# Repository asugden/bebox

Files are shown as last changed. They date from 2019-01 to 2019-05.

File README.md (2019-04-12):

#BEBOX

BeBox is a collection of tools for systems neuroscience. It includes three parts: designs for 3d printing, circuits and printed circuit boards (PCBs) for behavioral manipulation, and the Arduino code necessary for those circuits.

Many people are interested in only the 3d designs. In that case, all necessary hardware components are listed in the 3d designs directory. If you are interested in electronics, the BeBox Spritz and the BeBox Syringe Pump can both be used indepent of the BeBox system. The syringe pump can be integrated with BeBox. To start with BeBox, one has to order the boards (links can be found in the pcb directory), which come in orders of 3 from OSH Park, my preferred supplier. Note that BeBox is connected by 4-conductor headphone cables. They can be a bit hard to find. 3-conductor cables will not work.

##3D DESIGNS:
__All necessary components are listed in the README in the 3d directory.__

- .stl files  are final output files to be used with 3D printers.
- .scad files  are files written in OpenSCAD which define the .stl files and can be edited
- Some designs are made in Fusion 360 and are available upon request.

###bebox
- bebox bnc bottom.stl  the bottom of a case to hold bnc connectors for bebox
- bebox bnc top.stl  the top of the case to hold bnc connectors for bebox, which can have magnets inserted to allow stacking
- bebox button bottom.stl  the bottom of a case to hold bebox buttons, which also reports licks
- bebox button top.stl  the top of the case to hold bebox buttons
- bebox button 1.stl  a button cap with the number 1
- bebox button 2.stl  a button cap with the number 2
- bebox button 3.stl  a button cap with the number 3
- bebox button 4.stl  a button cap with the number 4
- bebox button e.stl  a button cap with the number e, for ensure
- bebox button q.stl  a button cap with the letter q, for quinine
- bebox main bottom.stl  the bottom of the case to hold the main bebox board
- bebox main top.stl  the top of the case to hold the main bebox board

###lickspout
__NOTE:__ the lickspouts should be printed with conductive PLA if conductive measurement is desired. The lickspout base should be printed in regular PLA. Conductive PLA plastic can be found at https://www.proto-pasta.com/collections/exotic-composite-pla/products/conductive-pla

- lickspout bitube.stl  a pre-made file to be printed with conductive filament that has two tubes, one regularly used for ensure high-calorie milkshake and one used for quinine diluted in water. This is designed for Tygon tubing of 1/16 inch inner diameter and 1/8 inch outer diameter (1.6 mm ID/3.2 mm OD). 
- lickspout unitube.stl  a pre-made file to be printed with conductive filament that has a single tube with a collection area, for training on only a high-calorie milkshake
- lickspout.scad  the file used to create both lickspout bitube and lickspout unitube. Adjustments can be made to the tube diameters at the top. Note that the curved pipe library is required for making changes: https://www.thingiverse.com/thing:71464
- lickspout bitube water.stl  a pre-made file to be printed with conductive filament that has two narrow-diameter tubes. The input tubing should be the same diameter, but the flow rate is decreased
- lickspout water.scad  the file used to create lickspout bitube water.stl. This, too, depends on the curved pipe library
- utilities.scad  a set of useful functions for OpenSCAD

###syringe-pump
The syringe pump is designed to tightly fit 20 ml syringes. All necessary mechanical and electrical components are listed in the README of the syringe 

- syringe pump box.stl  a file that defines the enclosure of the syringe pump including the motor and carriage
- syringe pump carriage.stl  the carriage that rides along bearings to compress the syringe. Note that it should be printed vertically rather than on a flat face.

###wheel
- wheel.stl  a pre-made file that can be printed on an average FDM printer with minimal layer heights. This requires two M4 nuts to be embedded and two M4x10 bolts to pinch the axles. I recommend using black PLA for the wheel as other colors may not correctly block the IR light of a beam breaker. We had problems with gray PLA being transparent to IR light.
- wheel axle.stl  a pre-made file of a short axle piece used to attach the wheel to the wheel holder. 2 are required
- wheel holder.stl  a pre-made file of a suspension system for the wheel, designed to fit into standard Thorlabs pieces. Requires two bearings from McMaster-Carr catalog number 57155K323 at $5.70 each to be inserted into the large central holes with the flanges outward. We hot glue them in, taking care not to get the glue into the bearings.
- wheel.scad  the file used to create wheel.stl. The wheel height, diameter, and tab spacing can all be changed. Note that a finer tab spacing requires narrower LED beam break detectors-- do not change without changing the encoder board.
- wheel holder.scad  the file used to create wheel axle.stl. The spring width, length, and thickness can all be adjusted and the wheel position will remain constant.

###wheel-accessories
- wheel run stopper.stl  a pre-made file that fits into a thorlabs part and applies some resistance to the wheel without disrupting its low inertia/springiness
- wheel run stopper.scad  the file used to create wheel run stopper.stl

###wheel-encoder
__NOTE:__ will be udpated in the near future

- wheel arduino holder.stl  a file to hold two LED beam breakers adjacent to the wheel
- wheel encoder board holder.stl  a file to allow an arduino to be bolted on to the holder such that it can be held next to the wheel

##ARDUINO CODE:
__NOTE:__ Has not yet been made compatible with the new BeBox system. Will be updated soon.

- BeBox  the code to run the BeBox system
	- mpr121.h  the header definitions required for the capacitance lick detection system

- Dumberbox  the code used to run the legacy Dumbberbox
- Encoder_Scanbox  the code used to run the legacy scanbox rotary encoder. Will be replaced with BeBox encoder software in early April 2019.

##PCB DESIGNS:
__All necessary components are listed in the README in the pcb directory.__

- .brd files  board files, matched with their schematic file, made in Eagle. You can bypass dealing with these files by directly ordering from OSH Park through a link I've set up. I am not affiliated with OSH Park.
- .sch files  schematic files, matched with a board file, made in Eagle. 

__NOTE:__  PCBs can be ordered from OSH Park for low costs. As of now, they are untested so please wait until late March 2019

- bebox_main  the main board, which takes power and connects directly to high-current behavior systems such as solenoids. It passed on the power given to it (usually 12V 2A supply, but can be 6-13 V and > 1 A). It connects via headphone cables to the daughter boards and lick spout. The connection ports are interchangeable.
- bebox_bnc  a daughterboard that allows for connections with Matlab via a Nidaq BNC system. It includes the lick detection and 4 output solenoids
- bebox_buttons  a daughterboard that allows control of solenoids and reports licking. There are two lick detection LEDs, just in case, and four buttons to control solenoids.
- bebox_encoder  a board that holds the rotary encoder IR beam breakers adjacent to the running wheel. This board can be configured in one of three ways: 
	1. For connection to the BeBox system, one can solder on an Adafruit Metro Mini (an Arduino Uno clone that has been miniaturized) and the i2c headphone jack. This will allow BeBox to directly interact with the running encoder. 
	2. To connect to Neurolabware's Scanbox, one can solder on an Adafruit Metro Mini and no headphone jacks. This can be plugged directly into the Scanbox computer via USB and it will be indistinguishable from an Arduino Uno.
	3. To use this with systems sensitive to electrical noise (electrophysiology), one can solder on the "ephys only" headphone jack, which transmits ground, power, and the output of the two beam breakers. This i2c cable can pass outside of a faraday cage to an external Arduino.

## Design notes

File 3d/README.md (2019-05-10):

## BeBox components (3 orders of all 3 boards)
The 3d Fusion 360 files for all of the BeBox pieces can be found here: https://a360.co/2JgHH8c

| Part name | Count | Cost per part | Total cost | Vendor | Vendor part number | 
|---|---|---|---|---|---|
| m4 x 10 bolt | 36 of 100 | 8.70 | 8.70 | McMaster | 91290A144 | 
| m4 nut | 36 of 100 | 8.08 | 8.08 | McMaster | 98676A200 | 
| m3 x 10 bolt | 6 of 100  | 7.36 | 7.36 | McMaster | 91290A115 | 
| m3 nut | 6 of 100  | 5.39 | 5.39 | McMaster | 98676A100 | 
| round magnet | 6 | 1.03 | 6.18 | McMaster | 5862K145 | 

## Lickspout components

| Part name | Count | Cost per part | Total cost | Vendor | Vendor part number | 
|---|---|---|---|---|---|
| conductive pla | 5g of 500 g | 49.99 | 49.99 | proto-pasta.com | CDP11705 | 
| tygon tubing | 5 ft | 1.35 | 1.35 | McMaster | 6546T33	 | 

## Syringe pump components

| Part name | Count | Cost per part | Total cost | Vendor | Vendor part number | 
|---|---|---|---|---|---|
| m4 x 10 bolt | 6 of 100 | 6.87 | 6.87 | McMaster | 91292A116 | 
| m4 nut | 6 of 100 | 2.45 | 2.45 | McMaster | 90591A255 | 
| linear motion shaft | 2 | 5.93 | 11.86 | McMaster | 6112K44 | 
| m8 threaded rod | 1 | 4.05 | 4.05 | McMaster | 98863A539 | 
| m8 square nut | 1 of 25  | 9.00 | 9.00 | McMaster | 90225A103 | 
| rod bearing | 1 | 8.66 | 8.66 | Mcmaster | 7804K145 | 
| spring, 3 count | 1 | 4.77 | 4.77 | McMaster | 9433K38 | 
| shaft coupler | 1 | 4.95 | 4.95 | Digikey  | 1528-2139-ND | 
| linear bearing | 2 | 2.95 | 5.90 | Digikey  | 1528-1287-ND | 

## Wheel components
The 3d Fusion 360 files for the wheel holder can be found here: https://a360.co/2J0girM

| Part name | Count | Cost per part | Total cost | Vendor | Vendor part number | 
|---|---|---|---|---|---|
| m4 x 10 bolt | 2 of 100 | 6.87 | 6.87 | McMaster | 91292A116 | 
| m4 nut | 2 of 100 | 2.45 | 2.45 | McMaster | 90591A255 | 
| bearing | 2 | 5.70 | 11.4 | McMaster | 57155K323 |

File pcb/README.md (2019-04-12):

__NOTE: I get no money from this and have no affiliation with OSH Park.__

## BeBox Main Trinket components

__CONFIRMED TO WORK__: https://oshpark.com/shared_projects/5AUOipvb

After creating this PCB, the Trinket became deprecated. I have created a newer, faster version based on the Adafruit ItsyBitsy M4.

| Part name | Count | Cost per part | Total cost | Vendor  | Vendor part number | 
|---|---|---|---|---|---|
| headone jack | 4 | 1.66 | 6.64 | Digikey | CP-435107RS-ND | 
| 4.7k resistor | 6 | 0.10 | 0.60 | Digikey | CF14JT4K70CT-ND | 
| power jack | 1 | 0.76 | 0.76 | Digikey | CP-102AH-ND | 
| screw terminal | 4 | 0.75 | 3.00 | Digikey | ED2740-ND | 
| switch | 1 | 11.56 | 11.56 | Digikey | 679-3961-ND | 
| diode | 4 | 0.11 | 0.44 | Digikey | 641-1310-1-ND | 
| transistor | 4 | 0.70 | 2.80 | Digikey | TIP122GOS-ND | 
| adafruit pro trinket | 1 | 9.95 | 9.95 | Digikey | 1528-1039-ND | 

## BeBox Main ItsyBitsy components

https://oshpark.com/shared_projects/iDtDUlNY

This new version is based on the Adafruit ItsyBitsy M4, but requires conversion for logic levels.

| Part name | Count | Cost per part | Total cost | Vendor  | Vendor part number | 
|---|---|---|---|---|---|
| headone jack | 4 | 1.66 | 6.64 | Digikey | CP-435107RS-ND | 
| 4.7k resistor | 8 | 0.10 | 0.60 | Digikey | CF14JT4K70CT-ND | 
| power jack | 1 | 0.76 | 0.76 | Digikey | CP-102AH-ND | 
| screw terminal | 4 | 0.75 | 3.00 | Digikey | ED2740-ND | 
| switch | 1 | 11.56 | 11.56 | Digikey | 679-3961-ND | 
| diode | 4 | 0.11 | 0.44 | Digikey | 641-1310-1-ND | 
| transistor | 4 | 0.70 | 2.80 | Digikey | TIP122GOS-ND | 
| adafruit itsybitsy m4  | 1 | 9.95 | 9.95 | Digikey | 1528-1039-ND | 
| logic level transistor | 2 | 0.47 | 0.94 | Digikey | 2N7000FS-ND | 
| 5V regulator | 1 | 6.81 | 20.43 | Digikey | 945-1037-ND | 

## BeBox BNC components

__CONFIRMED TO WORK__: https://oshpark.com/shared_projects/NPiqw07m

This box breaks out BNCs for communication with NIDAQ boards or the like. Currently, there is only a single lick output. Although the rest of BeBox can handle two capacitive sensors, the BNC board is not yet adapted for 4 solenoids and 2 licks. It is easy to change the code such that one of the solenoid inputs can be converted to a second lick output.

| Part name | Count | Cost per part | Total cost | Vendor  | Vendor part number | 
|---|---|---|---|---|---|
| bnc onnector | 5 | 1.65 | 8.25 | Digikey | A97555-ND | 
| headphone jack  | 1 | 1.66 | 1.66 | Digikey | CP-435107RS-ND | 
| i2c io expander | 1 | 1.05 | 1.05 | Digikey | MCP23008-E/P-ND | 
| 4.7k resistor | 5 | 0.10 | 0.50 | Digikey | CF14JT4K70CT-ND | 

## BeBox Button components

__CONFIRMED TO WORK__: https://oshpark.com/shared_projects/y1Swevmm

This box has buttons to control solenoids, as well as two LEDs that represent responses to different capacitance inputs. Our printer and slicer do a poor job keeping the inside of the LED holes clean, so it sometimes needs to be cleaned out with a 5 mm / 3/16 inch drill bit.

| Part name | Count | Cost per part | Total cost | Vendor  | Vendor part number | 
|---|---|---|---|---|---|
| headphone jack  | 1 | 1.66 | 1.66 | Digikey | CP-435107RS-ND | 
| i2c io expander | 1 | 1.05 | 1.05 | Digikey | MCP23008-E/P-ND | 
| switch (cherry) | 4 | 0.90 | 3.60 | Digikey | CH310-ND | 
| 330 resistor | 2 | 0.10 | 0.20 | Digikey | CF14JT330RCT-ND | 
| red led | 1 | 0.33 | 0.33 | Digikey | 160-1853-ND | 
| yellow led | 1 | 0.33 | 0.33 | Digikey | 160-1851-ND | 

## BeBox cables

You need 4-conductor 3.5 mm headphone cables to connect BeBox components. They can be any length. Two cables are required for the main 3 boxes, but more need to be used for the encoder or syringe pump. Below are options– you can choose how many to order of each size.

| Part name  | Count | Cost per part | Total cost | Vendor | Vendor part number | 
|---|---|---|---|---|---|
| 1' cable | 1 | 1.50 | 1.50 | Digikey | CAB-14163-ND | 
| 3' cable | 1 | 2.50 | 2.50 | Digikey | CAB-14164-ND | 
| 6' cable | 1 | 6.45 | 6.45 | Digikey | CP-354S-M/M-ND | 
| 1' cable | 1 | 1.89 | 1.89 | Monoprice | 24437 | 
| 3' cable | 1 | 2.29 | 2.29 | Monoprice | 18632 | 
| 6' cable | 1 | 2.59 | 2.59 | Monoprice | 18633 | 

## BeBox Capacitance Lickspout components

__CONFIRMED TO WORK__

There is no PCB here. We simply order a capacitance-sensing board and wire in the 4-conductor headphone cable. One prints a capacitance lickspout, uses an M3 bolt to fasten it to the lickspout holder, solder headers into the capacitance sensing board, heat a wire and shove it into the lickspout, and then attach it to the capacitance sensing board (again with headers, so that the lickspout can be replaced often).

__CONNECT BLACK -> SCL, YELLOW -> SDA, GREEN -> GND, RED -> VIN__

Note that wires are connected differently from dumberboxes.

| Part name | Count | Cost per part | Total cost | Vendor  | Vendor part number | 
|---|---|---|---|---|---|
| capacitance sensor | 1 | 7.95 | 7.95 | Digikey | CP-435107RS-ND | 
| 4-conductor wire | 1 | 6.25 | 6.25 | Digikey | CP-354S-ND | 
| female header | 1 | 0.32 | 0.32 | Digikey | S7000-ND | 

## BeBox Encoder components

https://oshpark.com/shared_projects/I9CImQTS

| Part name | Count | Cost per part | Total cost | Vendor  | Vendor part number | 
|---|---|---|---|---|---|
| ir beam break | 2 | 3.77 | 7.54 | Digikey | 1855-1043-ND | 
| 220 resistor | 2 | 0.10 | 0.20 | Digikey | CF14JT220RCT-ND | 
| | | | | | | 
| OPTIONAL: | | | | | | 
| adafruit metro mini | 1 | 12.50 | 12.50 | Digikey | 1528-1374-ND | 
| headphone jack | 1 | 1.66 | 1.66 | Digikey | CP-435107RS-ND | 

This board can be configured in one of three ways: 

1. For connection to the BeBox system, one can solder on an Adafruit Metro Mini (an Arduino Uno clone that has been miniaturized) and the i2c headphone jack. This will allow BeBox to directly interact with the running encoder.  __(both optional components)__
2. To connect to Neurolabware's Scanbox, one can solder on an Adafruit Metro Mini and no headphone jacks. This can be plugged directly into the Scanbox computer via USB and it will be indistinguishable from an Arduino Uno.  __(only optional metro mini)__
3. To use this with systems sensitive to electrical noise (electrophysiology), one can solder on the "ephys only" headphone jack, which transmits ground, power, and the output of the two beam breakers. This i2c cable can pass outside of a faraday cage to an external Arduino.  __(only optional headphone jack)__

## BeBox Syringe Pump components

https://oshpark.com/shared_projects/pRGppHBK

The syringe pump also requires a replaceable 20 ml syringe.

| Part name | Count | Cost per part | Total cost | Vendor  | Vendor part number | 
|---|---|---|---|---|---|
| adafruit itsybitsy m4 | 1 | 14.95 | 14.95 | Digikey | 1528-2619-ND | 
| stepper driver | 1 | 7.98 | 23.94 | Digikey | 1460-1159-ND | 
| 5V regulator | 1 | 6.81 | 20.43 | Digikey | 945-1037-ND | 
| oled screen | 1 | 19.95 | 19.95 | Digikey | 1528-1512-ND | 
| switch (cherry MX clear) | 1 | 0.90 | 0.90 | Digikey | CH310-ND | 
| rotary encoder (long) | 1 | 1.73 | 1.73 | Digikey | PEC11R-4020F-S0012-ND | 
| forward-backward toggle switch | 1 | 4.32 | 4.32 | Digikey | 360-3355-ND | 
| on-off toggle switch | 1 | 5.96 | 5.96 | Digikey | M2012S2A2A30-ND | 
| power jack | 1 | 0.76 | 0.76 | Digikey | CP-102AH-ND | 
| screw terminal | 4 | 0.75 | 3.00 | Digikey | ED2740-ND | 
| heat sink pad | 1 | 3.44 | 3.44 | Digikey | 3M10304-ND | 
| heatsink | 1 | 0.49 | 1.47 | Digikey | AE11388-ND | 
| logic level transistor | 2 | 0.47 | 0.94 | Digikey | 2N7000FS-ND | 
| 4.7k resistor | 4 | 0.10 | 0.40 | Digikey | CF14JT4K70CT-ND | 
| 3.5mm jack | 1 | 1.66 | 1.66 | Digikey | CP-435107RS-ND | 
| stepper motor (NEMA 17 200 steps/rev 12V) | 1 | 14.00 | 14.00 | Digikey | 1528-1062-ND | 

## BeBox Spritz components

https://oshpark.com/shared_projects/YoxiTIt1

This is a device to produce very small amounts of pressure for microinjections or puffing of drugs onto slices.

| Part name | Count | Cost per part | Total cost | Vendor | Vendor part number | 
|---|---|---|---|---|---|
| adafruit itsybitsy m4 | 1 | 14.95 | 14.95 | Digikey  | 1528-2619-ND | 
| 5V regulator | 1 | 6.81 | 20.43 | Digikey  | 945-1037-ND | 
| oled screen | 1 | 19.95 | 19.95 | Digikey  | 1528-1512-ND | 
| switch (cherry MX clear) | 2 | 0.90 | 1.80 | Digikey  | CH310-ND | 
| rotary encoder (long) | 1 | 1.73 | 1.73 | Digikey  | PEC11R-4020F-S0012-ND | 
| on-off toggle switch | 1 | 5.96 | 5.96 | Digikey  | M2012S2A2A30-ND | 
| power jack | 1 | 0.76 | 0.76 | Digikey  | CP-102AH-ND | 
| 150 resistor | 1 | 0.10 | 0.10 | Digikey  | CF14JT150RCT-ND | 
| 5mm red LED | 1 | 0.33 | 0.33 | Digikey  | 160-1853-ND | 
| 4.7k resistor | 1 | 0.10 | 0.10 | Digikey  | CF14JT4K70CT-ND | 
| diode | 1 | 0.11 | 0.11 | Digikey  | 641-1310-1-ND | 
| transistor | 1 | 0.70 | 0.70 | Digikey  | TIP122GOS-ND | 
| screw terminal | 1 | 0.75 | 0.75 | Digikey  | ED2740-ND | 
| | | | | | | 
| solenoid valve | 1 | 61.76 | 61.76 | Grainger | 6JJ52 | 
| pressure regulator | 1 | 69.90 | 69.90 | Festo | 159502 |

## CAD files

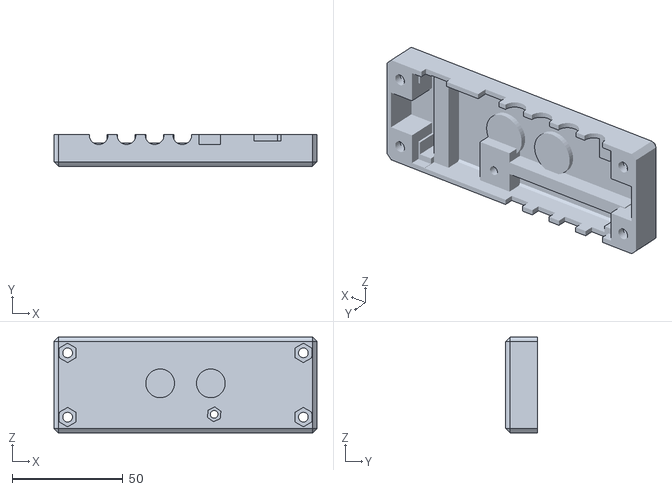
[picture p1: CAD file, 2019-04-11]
3d/bebox/bebox main bottom.stl
118.8 x 14.3 x 43.3

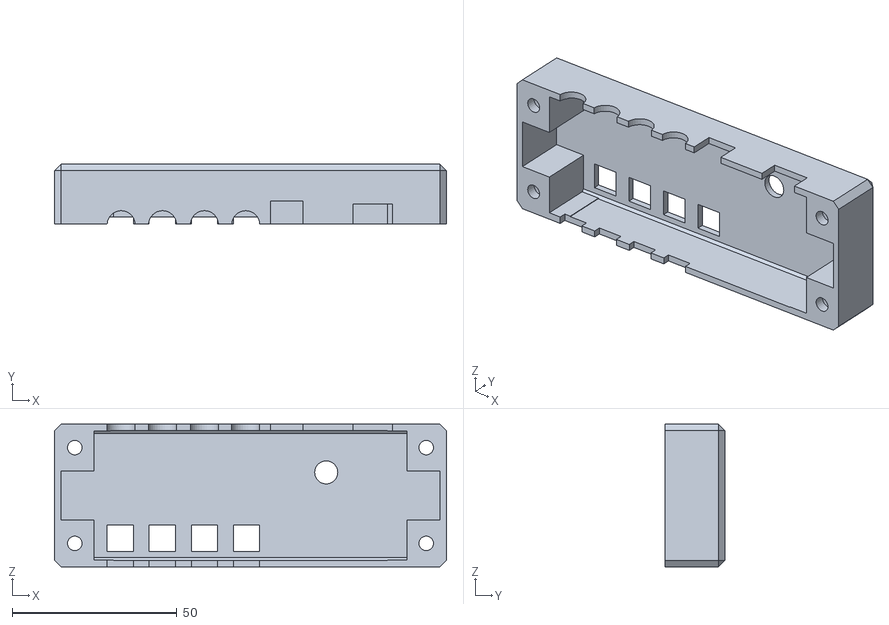
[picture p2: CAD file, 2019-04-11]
3d/bebox/bebox main top.stl
118.8 x 18.2 x 43.3

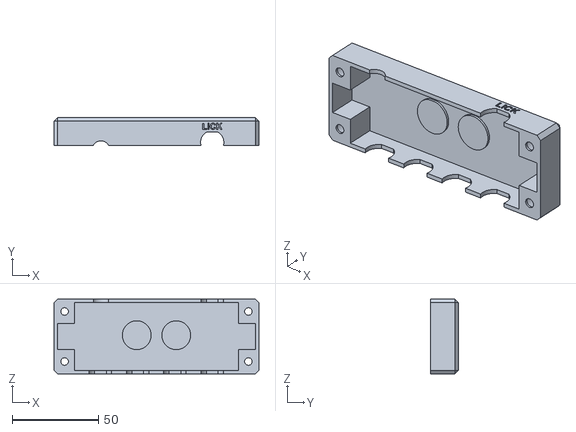
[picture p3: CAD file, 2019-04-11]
3d/bebox/bebox bnc top.stl
118.8 x 16.0 x 43.3

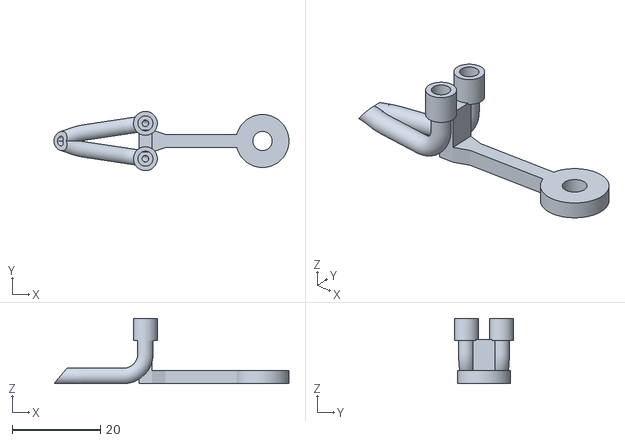
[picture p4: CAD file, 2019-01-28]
3d/lickspout/lickspout bitube water.stl
53.2 x 13.4 x 14.8

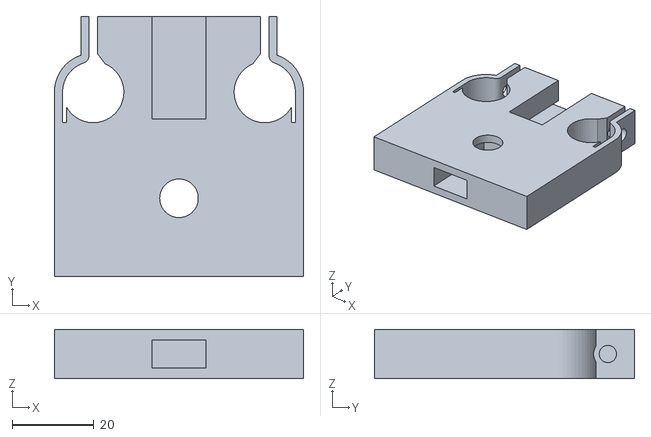
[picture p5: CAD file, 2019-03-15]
3d/syringe-pump/syringe pump carriage.stl
61.0 x 63.7 x 12.0

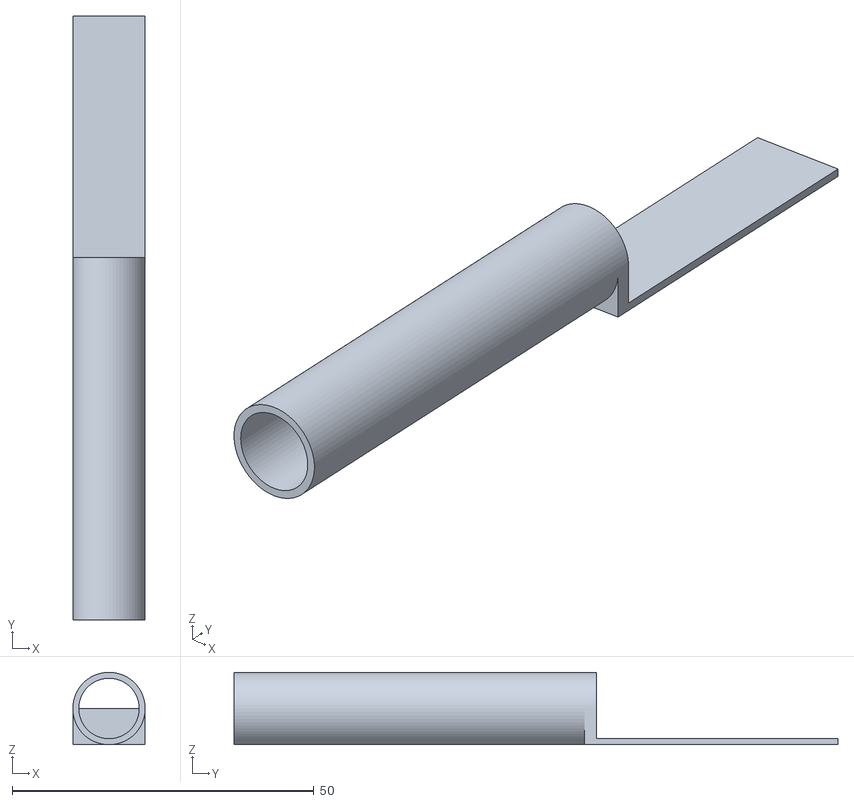
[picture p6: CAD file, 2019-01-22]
3d/wheel-accessories/wheel run stopper.stl
12.0 x 100.0 x 12.0

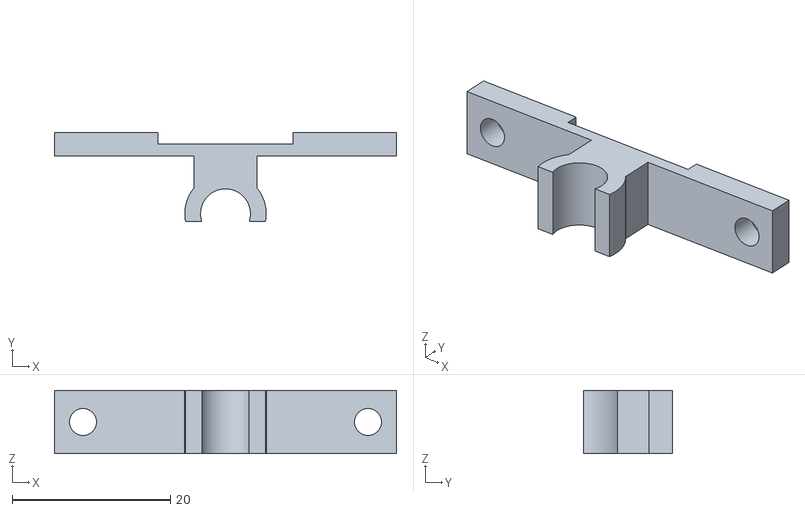
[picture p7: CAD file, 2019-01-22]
3d/wheel-encoder/wheel encoder board holder.stl
43.2 x 11.3 x 8.00

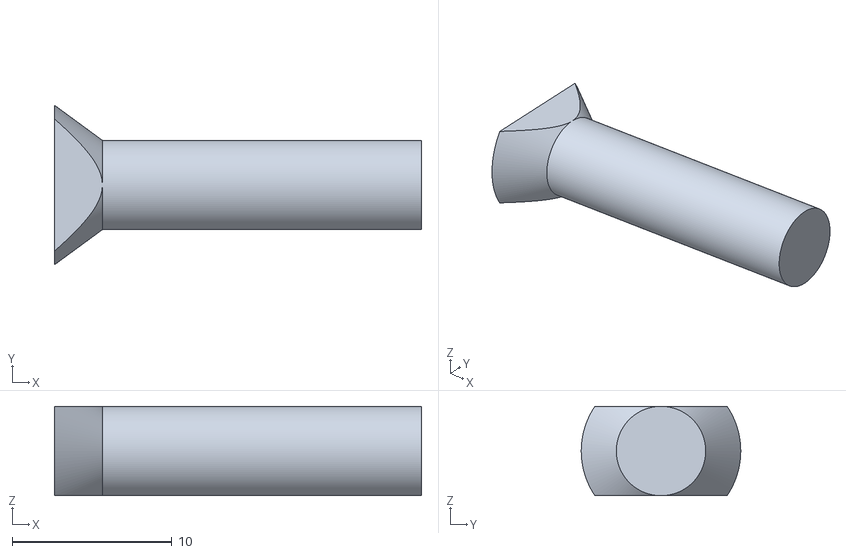
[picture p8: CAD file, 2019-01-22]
3d/wheel/wheel axle.stl
23.0 x 10.0 x 5.60

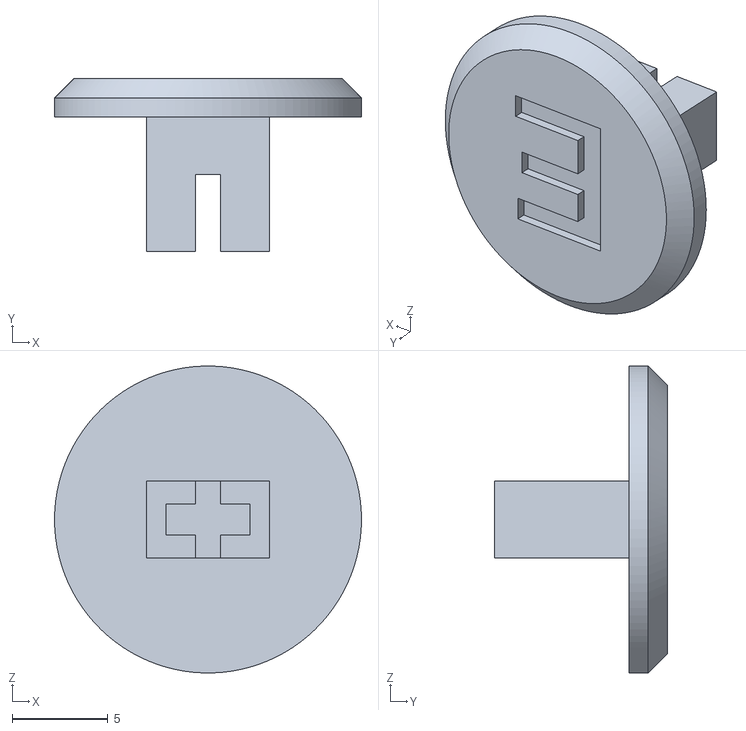
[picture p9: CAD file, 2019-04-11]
3d/bebox/bebox button E.stl
16.0 x 9.00 x 16.0

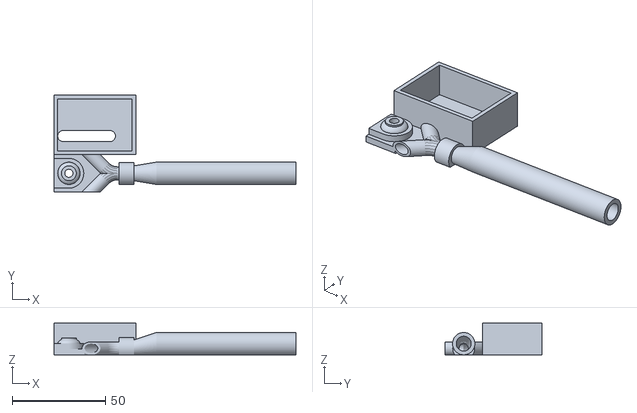
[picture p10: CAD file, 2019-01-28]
3d/lickspout/lickspout base capacitance.stl
130.0 x 52.0 x 17.0

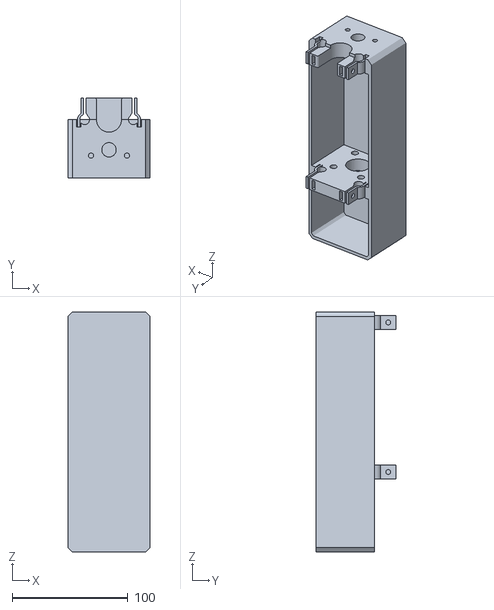
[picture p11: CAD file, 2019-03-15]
3d/syringe-pump/syringe pump box.stl
71.0 x 68.7 x 207.0

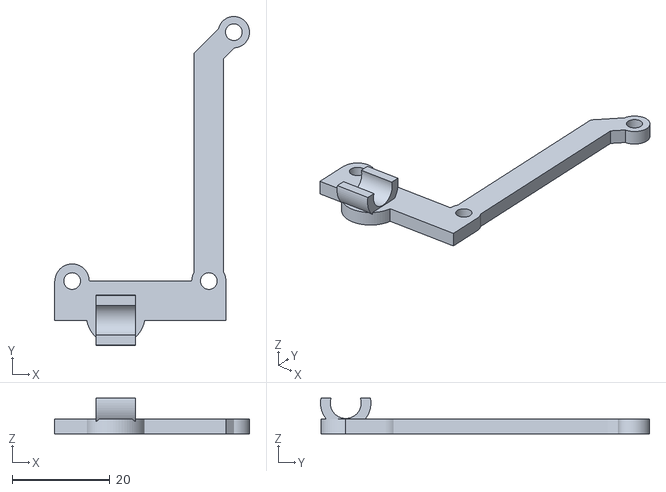
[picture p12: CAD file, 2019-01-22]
3d/wheel-encoder/wheel arduino holder.stl
39.8 x 67.2 x 7.30

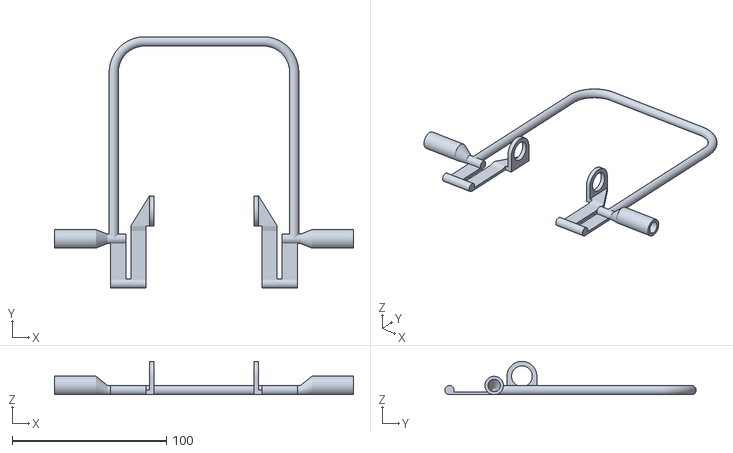
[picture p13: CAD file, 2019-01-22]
3d/wheel/wheel holder.stl
193.9 x 163.0 x 21.7

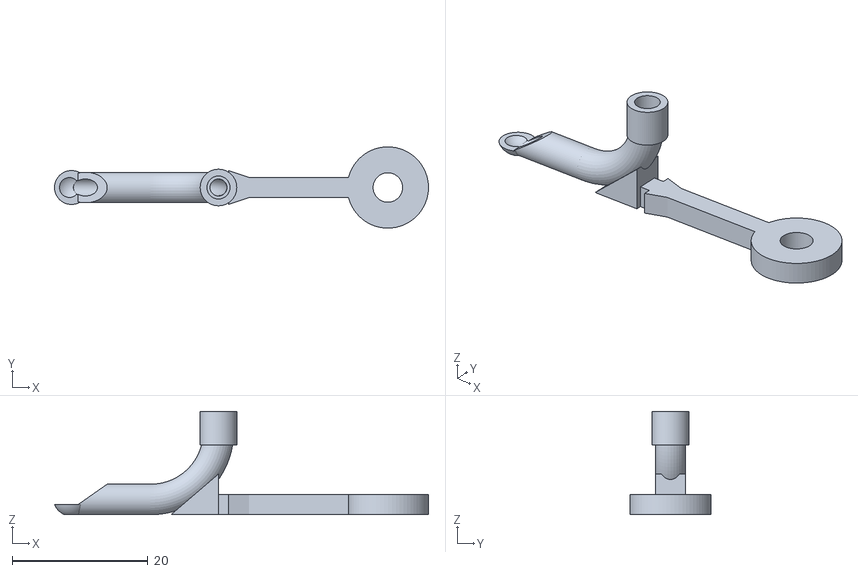
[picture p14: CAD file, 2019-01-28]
3d/lickspout/lickspout unitube.stl
55.2 x 12.0 x 15.2

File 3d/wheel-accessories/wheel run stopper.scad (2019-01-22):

$fn = 64;

translate([0, 0, 6])
rotate([90, 0, 0])
difference() {
    cylinder(r=6, h=60);
    translate([0, 0, -1])
    cylinder(r=5, h=62);
}

translate([-6, -2, 0])
cube([12, 42, 1]);

translate([-6, -2, 0])
cube([12, 2, 6]);

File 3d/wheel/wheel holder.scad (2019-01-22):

// 6 inch ball
// center is 11.6 inches from bottom plate
// center is 3.5 inches in front of posts

// thorlabs piece is 16.1 mm center-to-center
// vertical arms are 2 (or integers >= 2) inches in front of headpost posts
// vertical arms are 7 or 5 inches apart

// Mounting posts are expected to be 2 inches in front of headpost bars

// Move backwards 2 cm

use <utilities.scad>
use <curvedPipe.scad>
$fn = 64;

wheel_diameter = 14; // in cm
wheel_width = 6; // in cm
spring_width = 10; // in mm
spring_length = 30; // in mm, originally 50
spring_thickness = 1.8; // in mm
distance_from_wheel_to_headpost_supports = 10.4; // in cm, center-to-center
running_encoder = false;

//bearings 13.4 mm diameter
// Full width = 200 mm

module bearingCase(width, thickness) {
    union() {
        translate([0, 0, 12])
        rotate([0, 90, 0])
        difference() {
            union() {
                cylinder(r=13.4/2 + 3, h=3);
                translate([0, -13.4/2 - 3, 0])
                cube([12, 13.4 + 6, 3]);
            }
            
            translate([0, 0, -1])
            cylinder(r=13.4/2, h=5);
        }
        
        translate([0, -13.4/2 - 3, 0])
        linear_extrude(3)
        polygon([[0, 0], [3, 13.4 + 6], [width + 5, 0]]);
    
        // Toe plate
        translate([15, -13.4/2 - 3 - 3.3, 0])
        rotate([0, -90, 0])
        linear_extrude(width)
        polygon([[0, 0], [thickness, 0], [3, 3.3], [0, 3.3]]);
    }
}


module spring(w, l, d, fb=08) {
    // Backwards must be less than 2 inches - 50 mm
    // Forwards must be 1.5 inches- 38 mm
    // 7 
    // Total width must be less than 160 mm
    // FB is forward-back distance. originally 28. Now 08.
    
    backward = (l - fb)/2;
    forward = fb + backward;
    
    // Spring forward
    translate([0, -backward - 3, 0])
    cube([w, forward, d]);
    
    // Spring back
    translate([13, -backward - 3, 0])
    cube([w, backward, d]);
    
    // Hinge
    translate([0, -backward - 3, 0]) {
        cube([23, 3, 3]);
        translate([0, 0, 3])
        rotate([0, 90, 0])
        cylinder(r=3, h=23);
    }
    
    translate([13, -3, 0])
    cube([10, 3, 3]);
    
    translate([13, 0, 3])
    rotate([0, 90, 0])
    cylinder(r=3, h=12);
}

module post(ww) {
    translate([70, 0, 6])
    rotate([0, 90, 0])
    pipe(12.0, 8.0, 30 - 3.05);
    
    translate([ww/2 + 2.5 + 5 + 25, 0, 3])
    rotate([0, 90, 0])
    hullPipe(6, 12, -12/2 + 6/2, 2, 100 - (30 + ww/2 + 2.5 + 5 + 25));  
//    hullPipe(w, 12, -6 + w/2, 1, 15);
}

module encoderHolder(clearance=1.5) {
    // For Yuma E6B2-CWZ3E
    
    translate([0, -31, (40 + clearance)/2 + 2])
    rotate([-90, 0, 0])
    union() {
        // Faceplate
        difference() {
            cylinder(r=(40 + clearance)/2 + 2, h=3);
            translate([0, 0, -1])
            cylinder(r=(20.2 + clearance)/2, h=5);
            
            translate([0, 0, -1])
            difference() {
                cylinder(r=40/2 - 3.5, h=5);
                translate([0, 0, -1])
                cylinder(r=20.2/2 + 3.5, h=7);
                translate([-5, 8, -2])
                cube(10);
                
                rotate([0, 0, 120])
                translate([-5, 8, -2])
                cube(10);
                
                rotate([0, 0, 240])
                translate([-5, 8, -2])
                cube(10);
            }
        }
        
        // Body
        translate([0, 0, -42]) {
        difference() {
            union() {
                // Long body
                difference() {
                    cylinder(r=(40 + clearance)/2 + 2, h=42);
                    translate([0, 0, -1])
                    cylinder(r=(40 + clearance)/2, h=44);
                }
                
                // Rim
                difference() {
                    cylinder(r=(40 + clearance)/2 + 2, h=2);
                    translate([0, 0, -1])
                    cylinder(r=(40 + clearance)/2 - 2, h=4);
                }
            }
            
            translate([0, 0, -8]) {
                translate([-4.25, 15, -1])
                cube([9.5, 20, 50]);
                
                linear_extrude(50)
                polygon([
                    [0, 0],
                    [50*sin(45), 50*cos(45)],
                    [50*sin(165), 50*cos(165)],
                ]);
                
                linear_extrude(50)
                polygon([
                    [0, 0],
                    [50*sin(195), 50*cos(195)],
                    [50*sin(-45), 50*cos(-45)],
                ]);
                
            }
        }}
    }
}

module halfBracket(wd, ww, wf, sw, sl, sd, fb=8) {
    union() {
        post(ww);
        // Bearing, when translated correctly, is 25 mm ahead of 0
        translate([ww/2 + 2.5, fb+10, 0])
        bearingCase(sw, sd);
        translate([ww/2 + 2.5 + 5, 0, 0])
        spring(sw, sl, sd);
        
        translate([0, 0, 3])
        curvedPipe([
            [ww/2 + 2.5 + 13 + 3 + 5 + 5, 0, 0],
            [ww/2 + 2.5 + 13 + 3 + 5 + 5, wd/2 + 10 + 38 + 10, 0],
            [0, wd/2 + 10 + 38 + 10, 0],
        ], 2, [20], 6, 2, fn=128);
    }
}

module bracket(wd, ww, wf, sw, sl, sd, enc=true) {
    if (running_encoder) {
        difference() {
            union() {
                copy_mirror([1, 0, 0]) {
                    halfBracket(wd, ww, wf, sw, sl, sd);
                }
                meterAdd(wd, ww);
            }
            
            meterSubtract(wd, ww);
        }
    }
    else {
        union() {
            halfBracket(wd, ww, wf, sw, sl, sd);
            mirror([1, 0, 0])
            halfBracket(wd, ww, wf, sw, sl, sd);
        }
    }
}

module meterAdd(wd, ww) {
    //reflectanceMeter(wd, ww);
    pairedBreakDetector(wd, ww);
    translate([10, 5, 0])
    adafruitMetro(wd, ww);
    
}

module meterSubtract(wd, ww) {
    metro_w = 20;
    metro_h = 44;
    metro_d = 4.5;
    
    translate([24, 5, 0])
    translate([ww/2 + 22, wd/2 + 38 + 10 + 3 + 2 - metro_h - 3.5, 2])
    cube([metro_w + 0.5, metro_h + 0.5, 15]);
        
    translate([17, 0, -1])
    translate([ww/2 + 5, 38 + wd/2 - 3, 0])
    translate([0, -19.1/2, 2])
    cube([20, 19.1, 15]);
}

module breakDetector(wd, ww) {
    // Do not print! For reference only
    color([0.3, 0.3, 0.6])
    translate([-2.5, -18.6/2, 0])
    difference() {
        cube([15.2, 18.6, 5]);
        translate([-1, 8.6/2, -1])
        cube([13.2, 10, 7]);
    }
}

module pairedBreakDetector(wd, ww) {
    translate([ww/2 + 5, 38 + wd/2 - 3, 0]) {
        union() {
            //translate([0, 0, 1.5])
            //breakDetector(wd, ww);
            
            //translate([0, 0, 6.5])
            //breakDetector(wd, ww);
            
            translate([11, -18.6/2 - 2, 0])
            cube([15, 18.6 + 4, 1]);
        
            translate([11, -18.6/2 - 2 - 0.25, 0])
            cube([15, 2, 1.5 + 10 + 2]);
        
            translate([11, 18.6/2 + 0.25, 0])
            cube([15, 2, 1.5 + 10 + 2]);
        
            difference() {
                translate([15.2 - 2.5 - 5.5, -(18.6 + 0.5 + 4)/2, 0])
                cube([3 + 0.5 + 4, 18.6 + 0.5 + 4, 1 + 10 + 0.5 + 2]);
                
                translate([11.7, 5, -1])
                cube([10, 7.6, 20]);
                
                translate([11.7, -5 - 7.6, -1])
                cube([10, 7.6, 20]);
                
                translate([1.75, -8.3, 1])
                cube([10, 16.6, 15]);  
              
                translate([0, -19.1/2, 1.25])
                cube([13.2, 19.1, 10.5]);  
                
                translate([12, -1.5, 1.25])
                cube([5, 3, 11.5]);
            }
        }
    }    
}

module reflectanceMeter(wd, ww) {
    meter_w = 7.7;
    meter_h = 14;
    meter_d = 1.7;
    board_d = 1.5;
    
//    translate([0, 10, 0])
    translate([ww/2 + 3 + meter_d, wd/2 + 38 + 10 - meter_w/2 - 2 - 16, 0])
    difference() {
        cube([board_d + 2, meter_w + 4.5, meter_h + 2]);
        translate([-2, 2.25, 2])
        cube([board_d + 2, meter_w + 0.5, meter_h + 2]);
        // Wire output
        translate([-1, 2.25, 2 + meter_h - 3.5])
        cube([5, meter_w + 0.5, 20]);
    }
}
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

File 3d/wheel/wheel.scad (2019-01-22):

use <utilities.scad>

$fn = 256;

wheel_diameter = 14; // in cm
wheel_height = 6; // in cm
wheel_axle = 6; // diameter in mm

module encoderTabs(di, h) {
    tab_height = 8;
    
    difference() {
        translate([0, 0, h])
        pipe(di - 2, di - 6, tab_height);
        
        diff = 360.0/44.0;
        for (theta = [0:diff*2:359]) {
            rotate([0, 0, theta]) {
                translate([-di*PI/44/2, 0, h - 1])
                cube([di*PI/44, di, tab_height + 2]);
            }
        }
    }
}

module beamXZ(p1, p2) {
    l = sqrt((p2[0] - p1[0])*(p2[0] - p1[0]) + (p2[1] - p1[1])*(p2[1] - p1[1]));
    theta = asin((p2[1] - p1[1])/l);
    
    translate([p1[0], 0, p1[1]])
    rotate([0, -theta, 0])
    translate([0.5, -1, 0])
    cube([l, 2, 2]);
}

module beam(p1, p2, plane="xz") {
    l = sqrt((p2[0] - p1[0])*(p2[0] - p1[0]) + (p2[1] - p1[1])*(p2[1] - p1[1]));
    theta = atan2(p2[1] - p1[1], p2[0] - p1[0]);
    
    translate(plane == "xz" ? [p1[0], 0, p1[1]] : plane == "xy" ? [p1[0], p1[1], 0] : [0, p1[0], p1[1]])
    rotate(plane == "xz" ? [0, -theta, 0] : plane == "xy" ? [0, 0, theta] : [-theta, 0, 0])
    translate([0.5, -1, 0])
    cube([l, 2, 2]);
}

module beam3d(p1, p2) {
    l = sqrt((p2[0] - p1[0])*(p2[0] - p1[0]) + (p2[1] - p1[1])*(p2[1] - p1[1]) + (p2[2] - p1[2])*(p2[2] - p1[2]));
    
    crs = cross(p1 - p2, [1, 0, 0]);
    translate(p1)    
    rotate(a=angleBetweenVectors(p1 - p2, [1, 0, 0]), v=crs)
    
    translate([0.5, -1, 0])
    cube([l, 2, 2]);
}

module rim(di, h) {
    // just tire without rims is 33 g, 39 g with rims
    pipe(di, di - 2, h); 
    pipe(di, di - 6, 2);

    translate([0, 0, h - 5]) {
        difference() {
            pipe(di, di - 6, 5);
            cylinder(r1=di/2 - 1, r2= di/2 - 3, 3);
        }
    }
}

module arm(di, h, ax) {
    union() {
        translate([di/2 - 5, -1, 0])
        cube([4, 2, h]);
        
        translate([ax/2 + 0.5, -1, 0])
        cube([(di - ax)/2 - 1, 2, 2]);
        
        beam([ax/2, 0], [di/2 - 2, h - 2]);
        beam([ax/2, h - 2], [di/2 - 2, 0]);
        
        beam([di/3, 0], [di/2 - 2, h - 2]);
//        beam([ax/2, h - 2], [di/3, 0]);
        
//        beam([ax/2, 0], [di/2 - 2, h/2]);
    }
}

module support(di, h, ax, narms) { // weighs 25 g
    diff = 360/narms;
    difference() {
        union() {
            cylinder(r=ax/2 + 1.5, h=h);
            
            translate([0, 0, h - 9])
            embeddedM4(ax);
            
            rotate([0, 0, 180])
            mirror([0, 0, 1])
            translate([0, 0, -9])
            embeddedM4(ax);
             
            for (theta = [0:diff:359]) {
                rotate([0, 0, theta]) {
                    arm(di, h, ax);
                    beam3d([di/2*sin(0), di/2*cos(0), h], [di/4*sin(diff), di/4*cos(diff), 0]);
                    beam3d([0, (di/2 - 2), h/2], [2/6*di*sin(-diff), 2/6*di*cos(-diff), 0]);
                }
                
                 beam([2*di/6*sin(theta), 2*di/6*cos(theta)], [2*di/6*sin(theta+diff), 2*di/6*cos(theta+diff)], "xy");
            }
        }
        
        // Cube below 0 in z
        translate([-di, -di, -di*2])
        cube(di*2);
        
        // Cube above rim
        translate([-di, -di, h])
        cube(2*di);
        
        // Axle
        translate([0, 0, -1])
        cylinder(r=ax/2 + 0.3, h+2);

        // M4 bolt hole
        rotate([0, 0, 22.5])
        translate([0, 0, 6 + h - 9])
        rotate([0, 90, 0])
        cylinder(r=4.35/2.0, h=11);
        
        // M4 captive nut hole
        rotate([0, 0, 22.5])
        translate([ax/2 + 3.5/2 + 1, 0, 6 + h - 9])
        rotate([0, -90, 0])
        union() {
            hexagon(7.3, 3.5);
            translate([0, -7.3/2, -3.5/2])
            cube([10, 7.3, 3.5]);
        }
        
        rotate([0, 0, 22.5+180])
        union() {// [ 0.00, 0.00, 0.00 ]
            // M4 bolt hole
            translate([0, 0, 6 - 3])
            rotate([0, 90, 0])
            cylinder(r=4.35/2.0, h=11);
            
            // M4 captive nut hole
            translate([ax/2 + 3.5/2 + 1, 0, 6 - 3])
            mirror([0, 0, 1])
            rotate([0, -90, 0])
            union() {
                hexagon(7.3, 3.5);
                translate([0, -7.3/2, -3.5/2])
                cube([10, 7.3, 3.5]);
            }
        }
    }
    
}

module checkAxle(di, h, ax) {
    difference() {
        cylinder(r=ax/2 + 3, h=9);
        
        translate([0, 0, -1])
        cylinder(r=ax/2 + 0.3, 11);
    }
}

// size is the XY plane size, height in Z
module hexagon(size, height) {
  boxWidth = size/1.75;
  for (r = [-60, 0, 60]) rotate([0,0,r]) cube([boxWidth, size, height], true);
}

module embeddedM4(ax) {
    // center of nut at height 9
    rotate([0, 0, 22.5])
    union() {
        difference() {
            difference() {
                translate([0, -ax/2 - 2, 0])
                cube([7 + ax/2, ax + 4, 9]);
            
                translate([0, 0, -1])
                cylinder(r=ax/2 + 0.5, h=11);
            }
            
            translate([ax/2 + 3.5/2 + 1, 0, 6])
            rotate([0, -90, 0])
            union() {
                hexagon(7.3, 3.5);
                translate([0, -7.3/2, -3.5/2])
                cube([10, 7.3, 3.5]);
            }
            
            translate([0, 0, 6])
            rotate([0, 90, 0])
            cylinder(r=4.35/2.0, h=11);
        }
        
        translate([0, -ax/2 - 2, 0])
        rotate([-90, -90, 0])
        linear_extrude(ax + 4)
        polygon([[0, 0], [0, 7 + ax/2], [-7 - ax/2, 0]]);
    }
}

rim(wheel_diameter*10, wheel_height*10);
support(wheel_diameter*10, wheel_height*10, wheel_axle, 8);
encoderTabs(wheel_diameter*10, wheel_height*10);

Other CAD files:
3d/wheel/wheel.stl
3d/bebox/bebox button 4.stl
3d/lickspout/lickspout bitube.stl
3d/bebox/bebox button bottom.stl
3d/lickspout/lickspout base capacitance.scad
3d/bebox/bebox bnc bottom.stl
3d/bebox/bebox button 1.stl
3d/bebox/bebox button 2.stl
3d/bebox/bebox button 3.stl
3d/bebox/bebox button Q.stl
3d/bebox/bebox button top.stl
3d/lickspout/lickspout water.scad
3d/lickspout/lickspout.scad
3d/lickspout/utilities.scad

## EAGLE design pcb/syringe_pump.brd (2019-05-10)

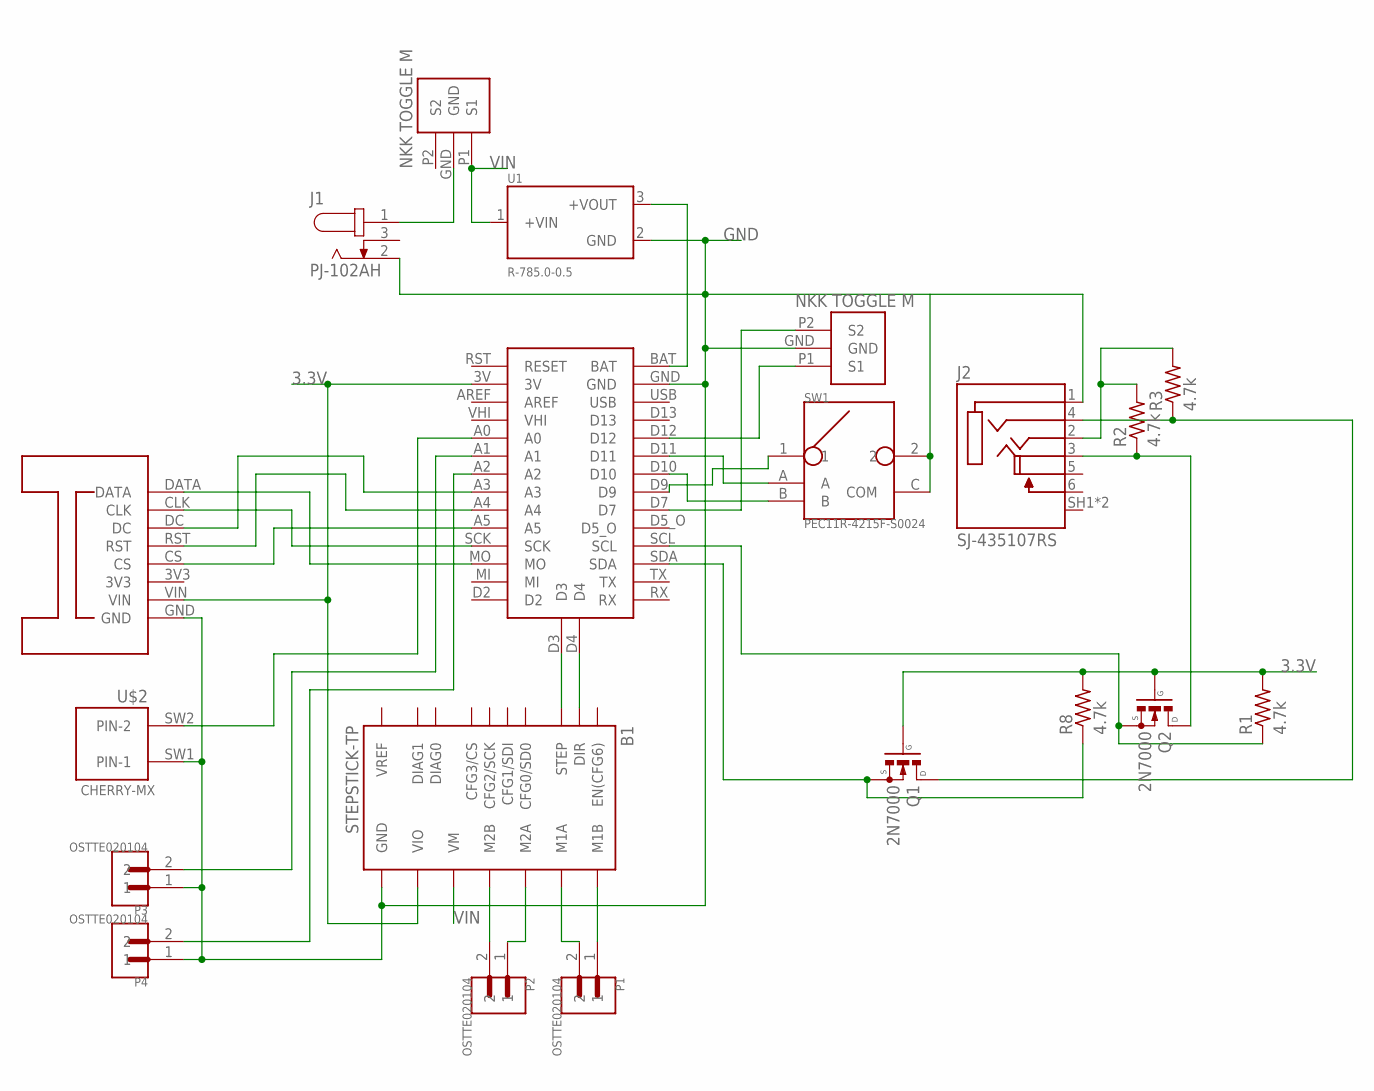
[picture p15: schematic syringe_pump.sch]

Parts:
B1: STEPSTICK-TP; STEPSTICK_TP
J1: PJ-102AH; CUI_PJ-102AH
J2: SJ-435107RS; CUI_SJ-435107RS
P1, P2, P3, P4: OSTTE020104; OST_OSTTE020104
Q1, Q2: 2N7000; TO92
R1, R2, R3, R8: 4.7k; 0207/10
SW1: PEC11R-4215F-S0024; SW_PEC11R-4215F-S0024
U1: R-785.0-0.5; RECOM_R-785.0-0.5
U$1: ITSYBITSYM4
U$2: CHERRY-MX
U$3: OLED_128X64
U$4: NKK_M2012S2A2A30
U$5: NKK_B13AH

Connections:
3.3V: B1.VIO, Q1.2 (G), Q2.2 (G), R1.2, R8.2, U$1.3V, U$3.VIN
GND: B1.GND@1 (GND), B1.GND@2 (GND), J1.2, J2.1 (SLEEVE), P3.1, P4.1, SW1.2, SW1.C (COM), U1.2 (GND), U$1.GND, U$2.SW1 (PIN-1), U$3.GND, U$5.GND
unnamed: Q1.1 (S), R8.1, U$1.SDA
unnamed: J2.2 (TIP), R2.2, R3.2
unnamed: B1.STEP, U$1.D3
unnamed: B1.DIR, U$1.D4
unnamed: Q2.1 (S), R1.1, U$1.SCL
unnamed: B1.M2B, P2.2
unnamed: B1.M2A, P2.1
unnamed: B1.M1B, P1.1
unnamed: B1.M1A, P1.2
unnamed: J2.3 (RING1), Q2.3 (D), R2.1
unnamed: J2.4 (RING2), Q1.3 (D), R3.1
unnamed: U$1.MO, U$3.DATA
unnamed: U$1.A3, U$3.DC
unnamed: U$1.A5, U$3.CS
unnamed: U$1.A4, U$3.RST
unnamed: P4.2, U$1.A2
unnamed: U$1.SCK, U$3.CLK
unnamed: J1.1, U$4.GND
unnamed: P3.2, U$1.A1
unnamed: U$1.A0, U$2.SW2 (PIN-2)
unnamed: U$1.D12, U$5.P1 (S1)
unnamed: U$1.D7, U$5.P2 (S2)
unnamed: SW1.A, U$1.D11
unnamed: SW1.B, U$1.D10
unnamed: SW1.1, U$1.D9
unnamed: U1.3 (+VOUT), U$1.BAT
VIN: B1.VM, U1.1 (+VIN), U$4.P1 (S1)

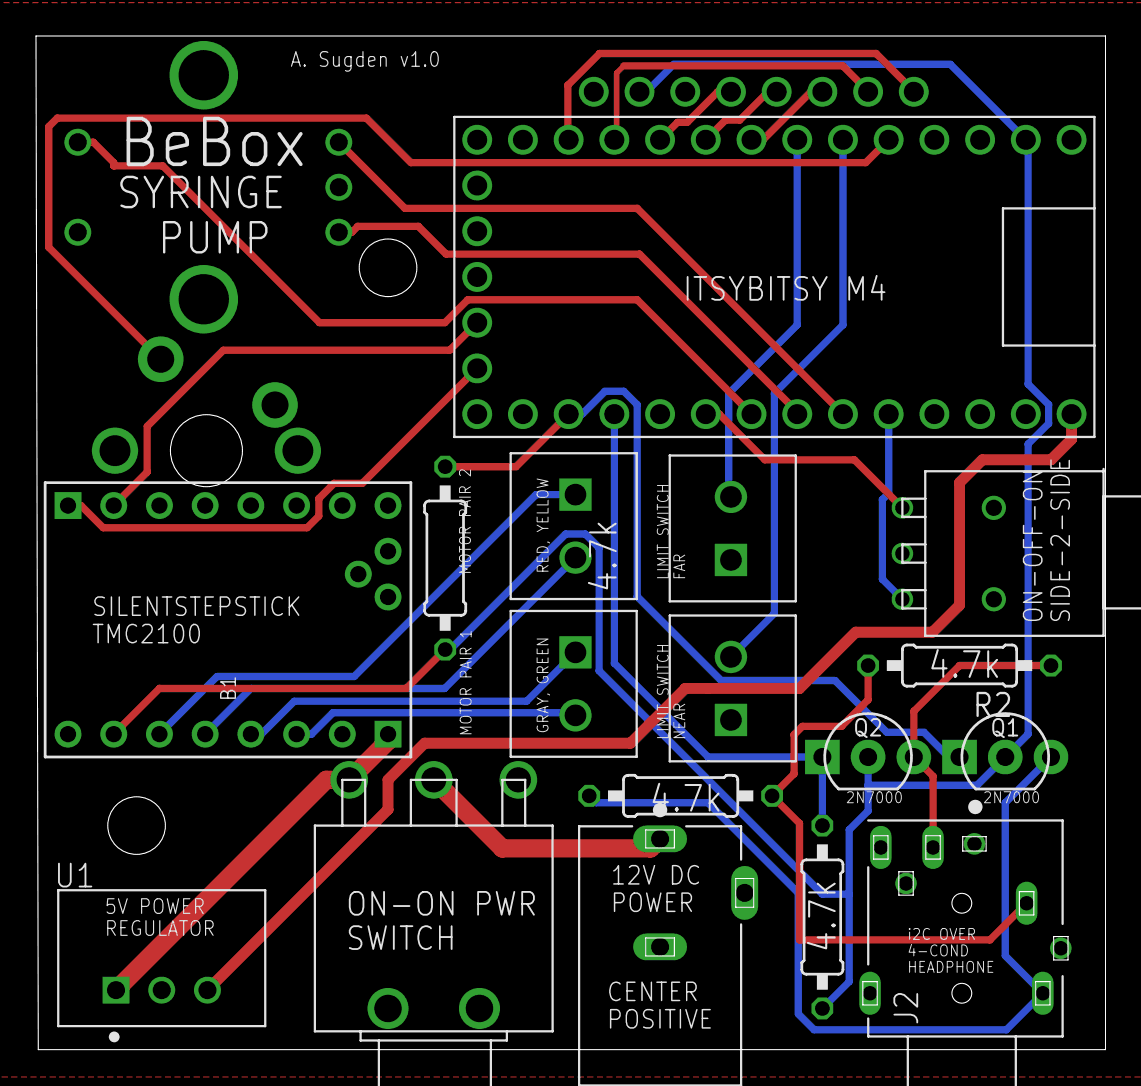
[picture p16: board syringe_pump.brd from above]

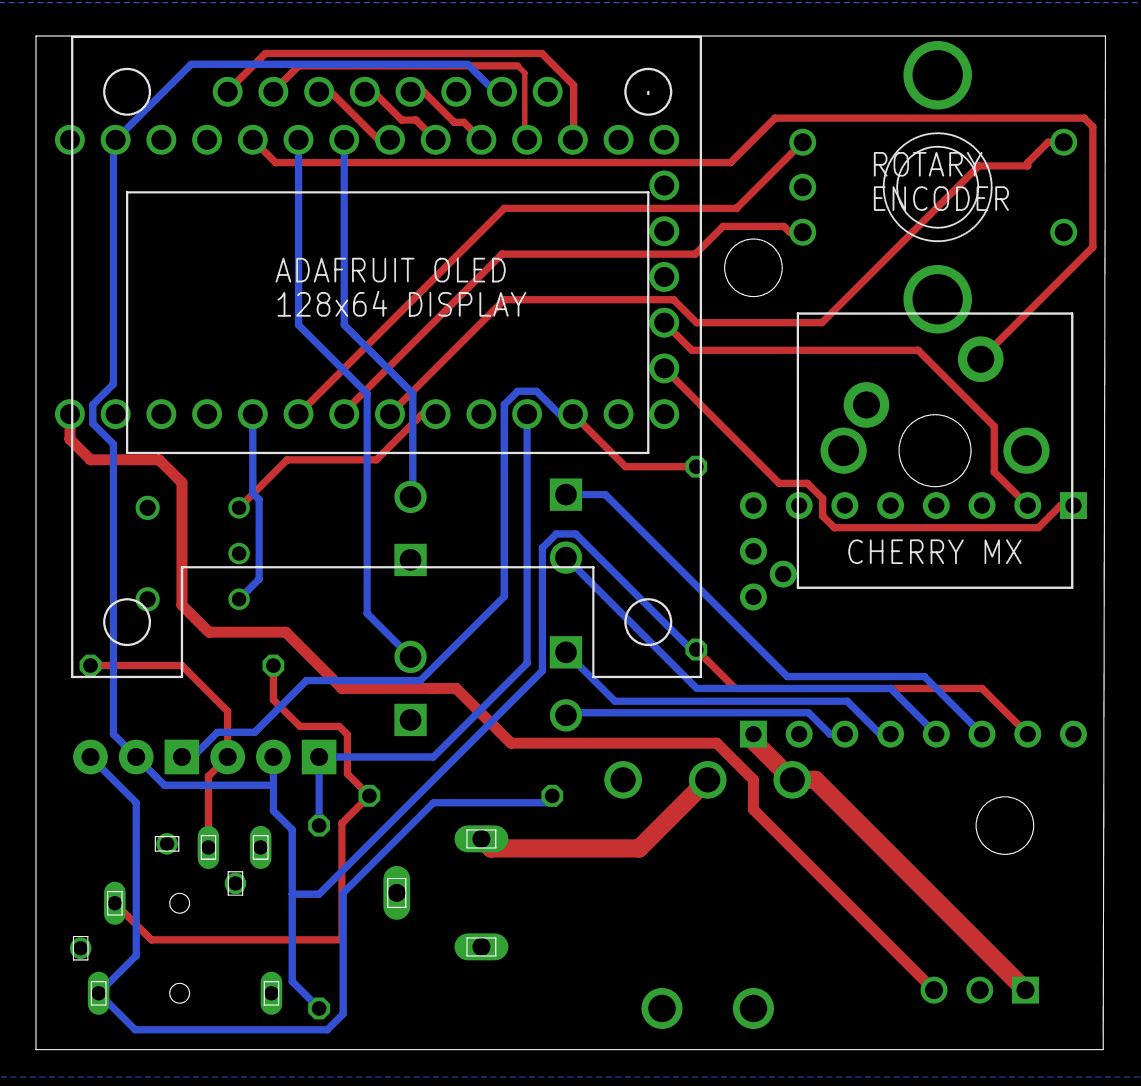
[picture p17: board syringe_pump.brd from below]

Board: 2 copper layers, 59.4 x 56.3 mm, 20 parts (3 on the bottom side), 29 nets.

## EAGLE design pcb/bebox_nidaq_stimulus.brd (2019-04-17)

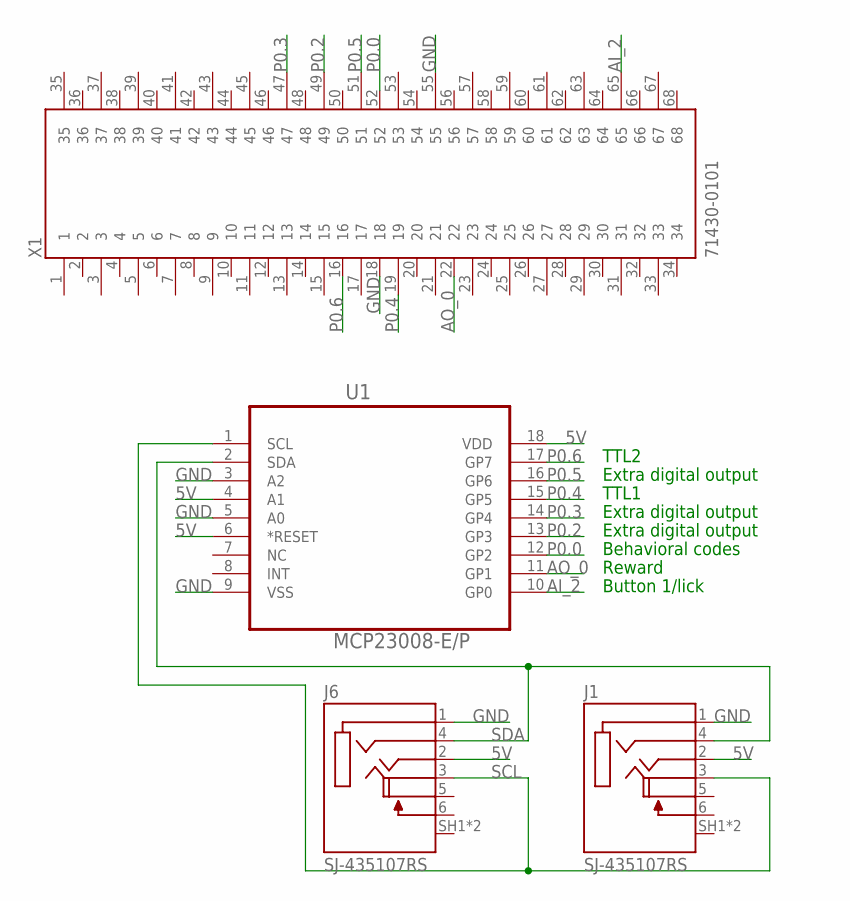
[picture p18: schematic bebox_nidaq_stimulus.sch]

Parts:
J1, J6: SJ-435107RS; CUI_SJ-435107RS
U1: MCP23008-E/P; DIP254P762X533-18
X1: 71430-0101; MOLEX_71430-0101

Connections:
5V: J1.2 (TIP), J6.2 (TIP), U1.4 (A1), U1.6 (*RESET), U1.18 (VDD)
AI_2: U1.10 (GP0), X1.65
AO_0: U1.11 (GP1), X1.22
GND: J1.1 (SLEEVE), J6.1 (SLEEVE), U1.3 (A2), U1.5 (A0), U1.9 (VSS), X1.18, X1.55
P0.0: U1.12 (GP2), X1.52
P0.2: U1.13 (GP3), X1.49
P0.3: U1.14 (GP4), X1.47
P0.4: U1.15 (GP5), X1.19
P0.5: U1.16 (GP6), X1.51
P0.6: U1.17 (GP7), X1.16
SCL: J1.3 (RING1), J6.3 (RING1), U1.1 (SCL)
SDA: J1.4 (RING2), J6.4 (RING2), U1.2 (SDA)

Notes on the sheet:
Reward
Behavioral codes
Button 1/lick
TTL1
TTL2
Extra digital output

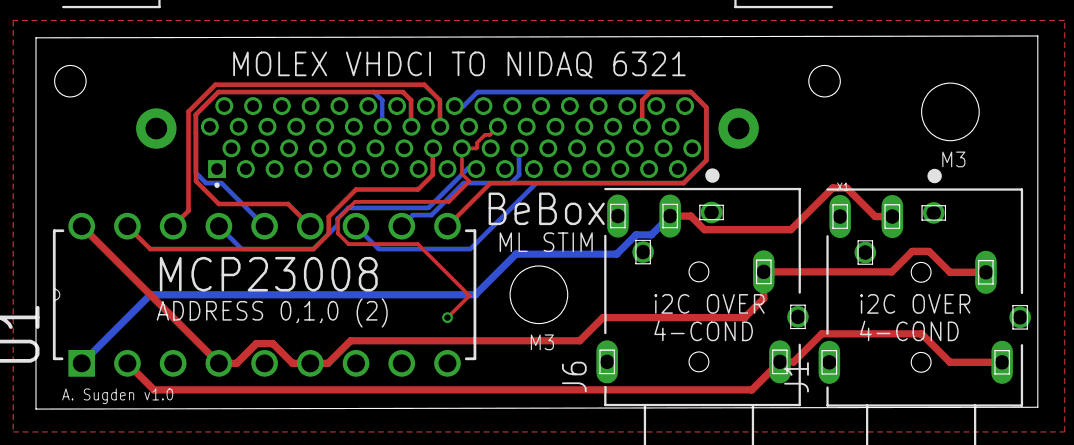
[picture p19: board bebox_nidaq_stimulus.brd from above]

Board: 2 copper layers, 55.7 x 20.7 mm, 4 parts (0 on the bottom side), 12 nets.

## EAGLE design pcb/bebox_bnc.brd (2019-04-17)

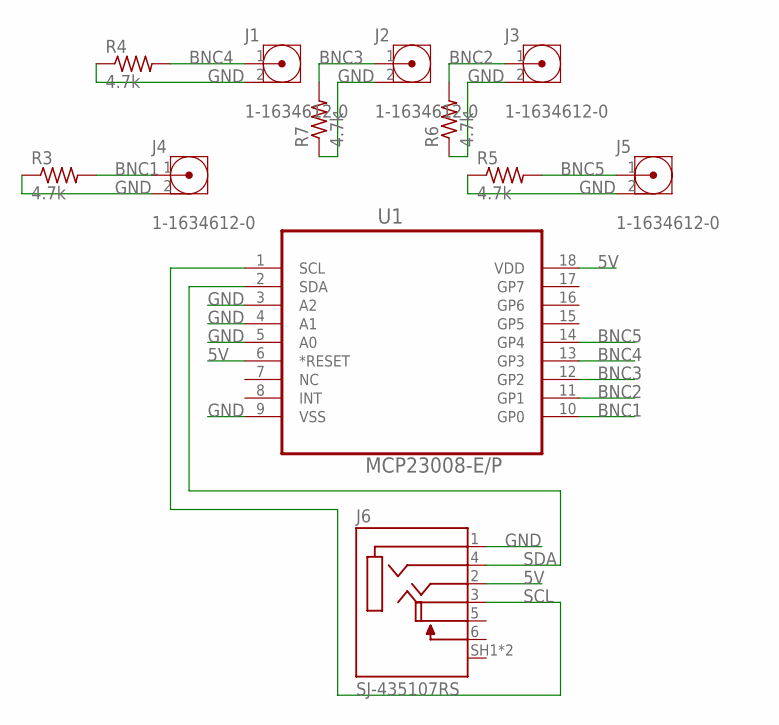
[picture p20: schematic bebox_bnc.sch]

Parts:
J1, J2, J3, J4, J5: 1-1634612-0; TE_1-1634612-0
J6: SJ-435107RS; CUI_SJ-435107RS
R3, R4, R5, R6, R7: 4.7k; 0207/10
U1: MCP23008-E/P; DIP254P762X533-18

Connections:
5V: J6.2 (TIP), U1.6 (*RESET), U1.18 (VDD)
BNC1: J4.1, R3.2, U1.10 (GP0)
BNC2: J3.1, R6.2, U1.11 (GP1)
BNC3: J2.1, R7.2, U1.12 (GP2)
BNC4: J1.1, R4.2, U1.13 (GP3)
BNC5: J5.1, R5.2, U1.14 (GP4)
GND: J1.2, J2.2, J3.2, J4.2, J5.2, J6.1 (SLEEVE), R3.1, R4.1, R5.1, R6.1, R7.1, U1.3 (A2), U1.4 (A1), U1.5 (A0), U1.9 (VSS)
SCL: J6.3 (RING1), U1.1 (SCL)
SDA: J6.4 (RING2), U1.2 (SDA)

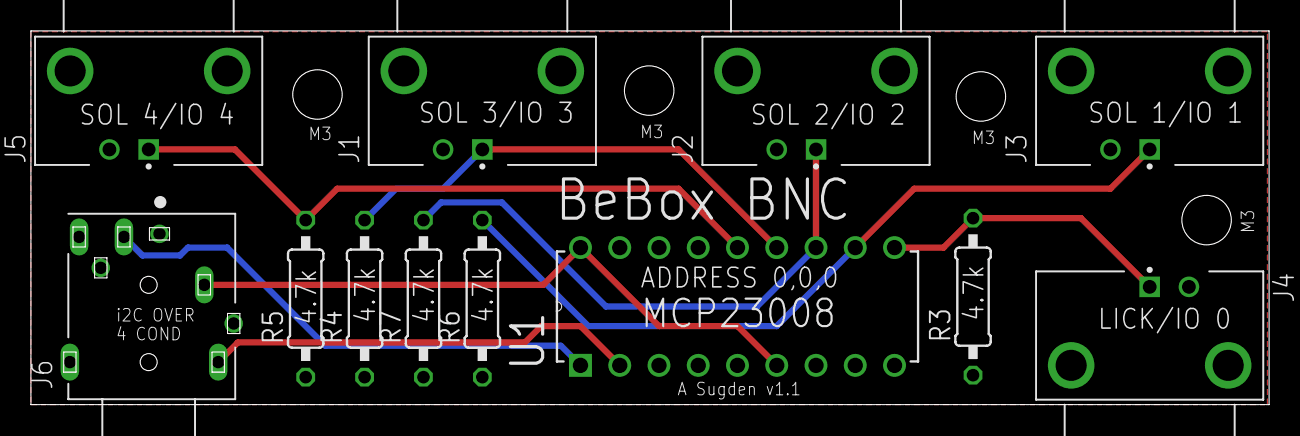
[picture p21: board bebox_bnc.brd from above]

Board: 2 copper layers, 80.1 x 24.2 mm, 12 parts (0 on the bottom side), 9 nets.

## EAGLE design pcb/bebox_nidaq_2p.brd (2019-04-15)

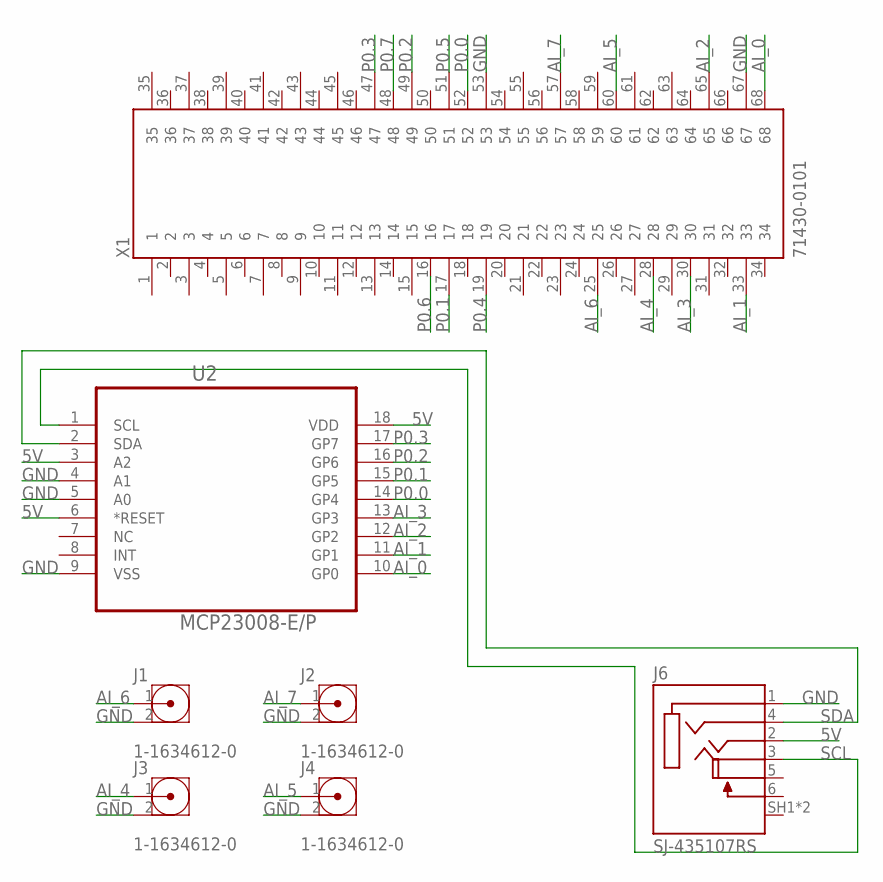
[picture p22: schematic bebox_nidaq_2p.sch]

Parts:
J1, J2, J3, J4: 1-1634612-0; TE_1-1634612-0
J6: SJ-435107RS; CUI_SJ-435107RS
U2: MCP23008-E/P; DIP254P762X533-18
X1: 71430-0101; MOLEX_71430-0101

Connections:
5V: J6.2 (TIP), U2.3 (A2), U2.6 (*RESET), U2.18 (VDD)
AI_0: U2.10 (GP0), X1.68
AI_1: U2.11 (GP1), X1.33
AI_2: U2.12 (GP2), X1.65
AI_3: U2.13 (GP3), X1.30
AI_4: J3.1, X1.28
AI_5: J4.1, X1.60
AI_6: J1.1, X1.25
AI_7: J2.1, X1.57
GND: J1.2, J2.2, J3.2, J4.2, J6.1 (SLEEVE), U2.4 (A1), U2.5 (A0), U2.9 (VSS), X1.53, X1.67
P0.0: U2.14 (GP4), X1.52
P0.1: U2.15 (GP5), X1.17
P0.2: U2.16 (GP6), X1.49
P0.3: U2.17 (GP7), X1.47
P0.4: X1.19
P0.5: X1.51
P0.6: X1.16
P0.7: X1.48
SCL: J6.3 (RING1), U2.1 (SCL)
SDA: J6.4 (RING2), U2.2 (SDA)

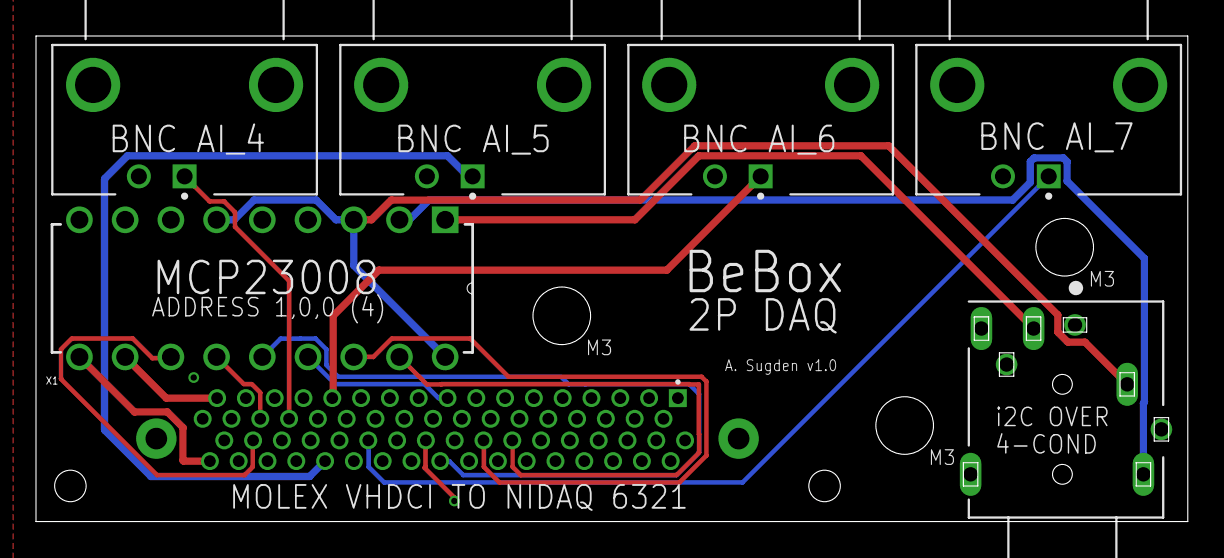
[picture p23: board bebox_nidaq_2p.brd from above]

Board: 2 copper layers, 64.0 x 27.0 mm, 7 parts (0 on the bottom side), 16 nets.

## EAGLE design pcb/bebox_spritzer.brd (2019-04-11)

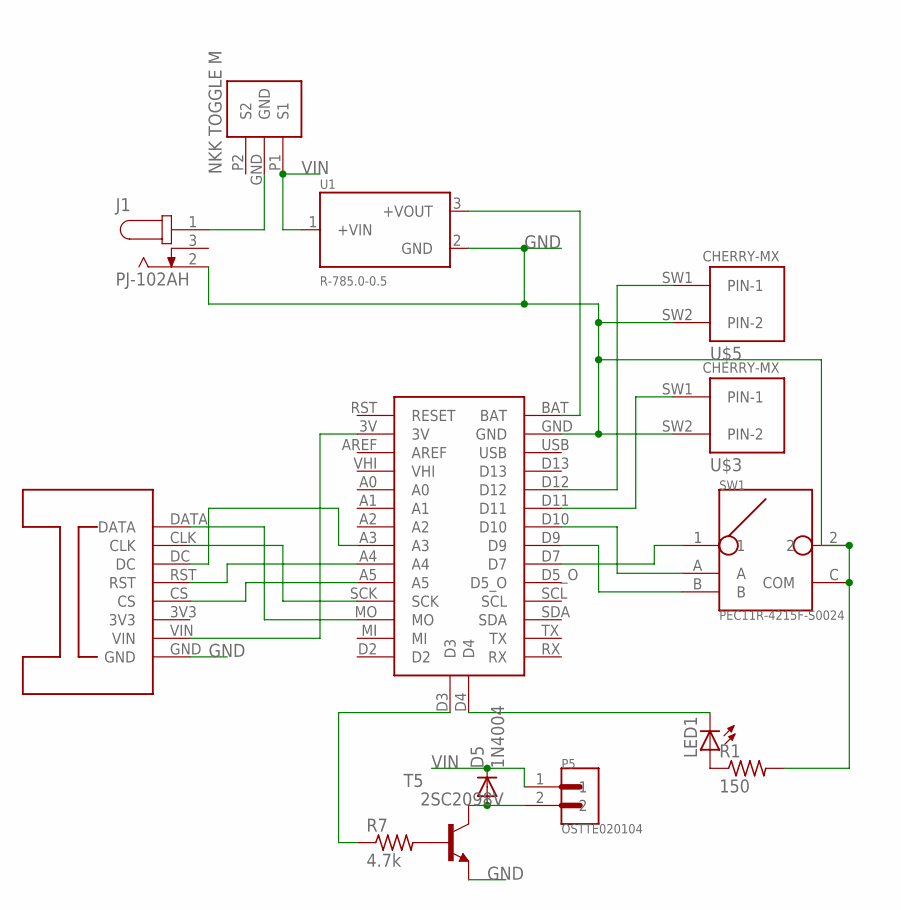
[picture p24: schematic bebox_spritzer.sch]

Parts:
D5: 1N4004; DO41-10
J1: PJ-102AH; CUI_PJ-102AH
LED1: LED5MM
P5: OSTTE020104; OST_OSTTE020104
R1: 150; 0207/10
R7: 4.7k; 0207/10
SW1: PEC11R-4215F-S0024; SW_PEC11R-4215F-S0024
T5: 2SC2098V; TO220AV
U1: R-785.0-0.5; RECOM_R-785.0-0.5
U$1: ITSYBITSYM4
U$2: OLED_128X64
U$3, U$5: CHERRY-MX
U$4: NKK_M2012S2A2A30

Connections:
GND: J1.2, R1.2, SW1.2, SW1.C (COM), T5.3 (E), U1.2 (GND), U$1.GND, U$2.GND, U$3.SW2 (PIN-2), U$5.SW2 (PIN-2)
unnamed: LED1.A, R1.1
unnamed: R7.1, U$1.D3
unnamed: LED1.K (C), U$1.D4
unnamed: U$1.D12, U$5.SW1 (PIN-1)
unnamed: U$1.MO, U$2.DATA
unnamed: U$1.SCK, U$2.CLK
unnamed: U$1.A3, U$2.DC
unnamed: U$1.A4, U$2.RST
unnamed: U$1.A5, U$2.CS
unnamed: R7.2, T5.1 (B)
unnamed: D5.A, P5.2, T5.2 (C)
unnamed: U$1.3V, U$2.VIN
unnamed: SW1.A, U$1.D10
unnamed: U$1.D11, U$3.SW1 (PIN-1)
unnamed: SW1.B, U$1.D9
unnamed: SW1.1, U$1.D7
unnamed: J1.1, U$4.GND
unnamed: U1.3 (+VOUT), U$1.BAT
VIN: D5.C, P5.1, U1.1 (+VIN), U$4.P1 (S1)

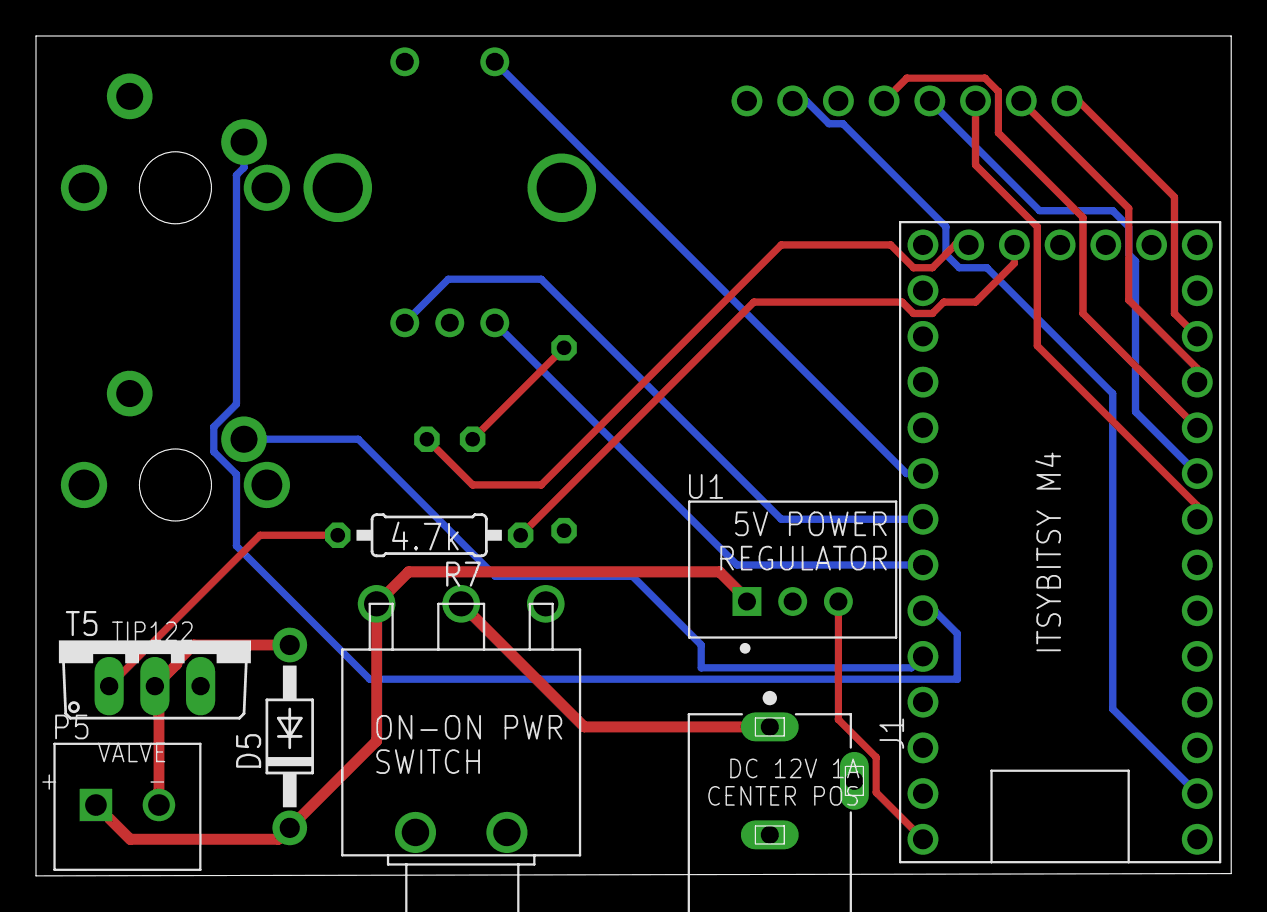
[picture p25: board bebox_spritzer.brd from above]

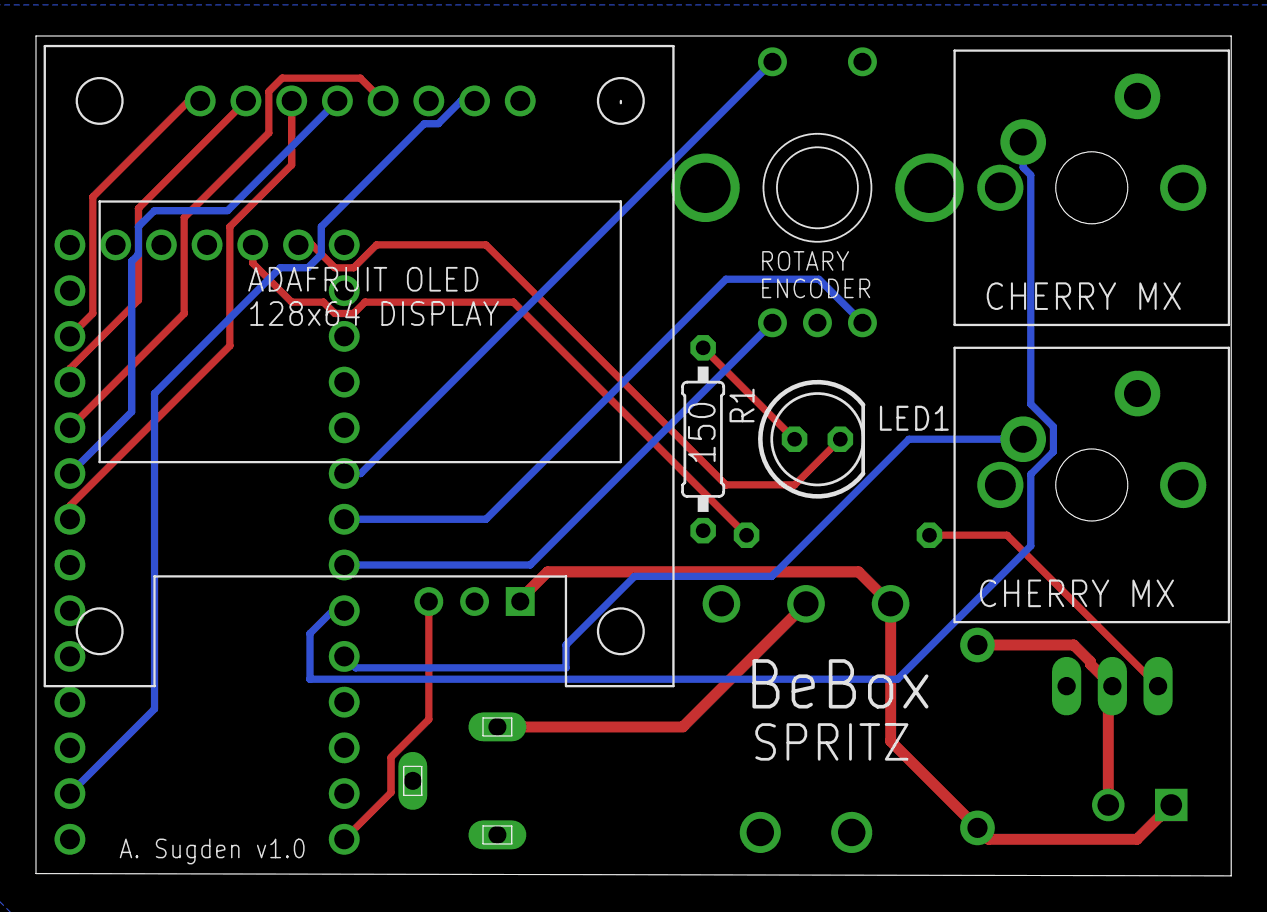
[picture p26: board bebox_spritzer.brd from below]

Board: 2 copper layers, 66.4 x 46.7 mm, 14 parts (6 on the bottom side), 20 nets.

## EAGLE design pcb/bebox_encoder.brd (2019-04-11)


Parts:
IC1: 2590
J1, J6: SJ-435107RS; CUI_SJ-435107RS
R1, R2: 220; AXIAL-0.3
U1, U2: GP1A57HR

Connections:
5V: IC1.4 (5V), J1.2 (TIP), J6.2 (TIP), U1.1, U1.3, U2.1, U2.3
GND: IC1.5 (GND_1), J1.1 (SLEEVE), J6.1 (SLEEVE), R1.P$2 (2), R2.P$2 (2), U1.5, U2.5
unnamed: R2.P$1 (1), U2.2
unnamed: R1.P$1 (1), U1.2
unnamed: IC1.17 (I/O_2), J6.4 (RING2), U1.4
unnamed: IC1.18 (I/O_3), J6.3 (RING1), U2.4
SCL: IC1.14 (A5), J1.3 (RING1)
SDA: IC1.13 (A4), J1.4 (RING2)



Board: 2 copper layers, 58.9 x 21.6 mm, 7 parts (4 on the bottom side), 8 nets.

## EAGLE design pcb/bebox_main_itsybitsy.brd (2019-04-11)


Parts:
D2, D3, D4, D5: 1N4004; DO41-10
J1, J2, J4: SJ-435107RS; CUI_SJ-435107RS
J6: PJ-102AH; CUI_PJ-102AH
LICK: SJ-435107RS; CUI_SJ-435107RS
P2, P3, P4, P5: OSTTE020104; OST_OSTTE020104
POWER: SWITCH_APEM_5636AB9; 320-916
Q1, Q2: 2N7000; TO92
R1, R2, R3, R4, R5, R6, R7, R8: 4.7k; 0207/10
T2, T3, T4, T5: 2SC2098V; TO220AV
U1: R-785.0-0.5; RECOM_R-785.0-0.5
U$1: ITSYBITSYM4

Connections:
3.3V: Q1.2 (G), Q2.2 (G), R1.1, R2.1, U$1.3V
5V: J1.2 (TIP), J2.2 (TIP), J4.2 (TIP), LICK.2 (TIP), R3.2, R8.1, U1.3 (+VOUT), U$1.BAT
12V: D2.C, D3.C, D4.C, D5.C, P2.1, P3.1, P4.1, P5.1, POWER.1 (O), U1.1 (+VIN)
GND: J1.1 (SLEEVE), J2.1 (SLEEVE), J4.1 (SLEEVE), J6.2, LICK.1 (SLEEVE), T2.3 (E), T3.3 (E), T4.3 (E), T5.3 (E), U1.2 (GND), U$1.GND
unnamed: J6.1, POWER.2
unnamed: Q1.1 (S), R1.2, U$1.SDA
unnamed: Q2.1 (S), R2.2, U$1.SCL
unnamed: R4.2, T2.1 (B)
unnamed: D2.A, P2.2, T2.2 (C)
unnamed: R5.2, T3.1 (B)
unnamed: D3.A, P3.2, T3.2 (C)
unnamed: R6.2, T4.1 (B)
unnamed: D4.A, P4.2, T4.2 (C)
unnamed: R7.2, T5.1 (B)
unnamed: D5.A, P5.2, T5.2 (C)
unnamed: R7.1, U$1.D9
unnamed: R6.1, U$1.D10
unnamed: R5.1, U$1.D11
unnamed: R4.1, U$1.D12
SCL: J1.3 (RING1), J2.3 (RING1), J4.3 (RING1), LICK.3 (RING1), Q2.3 (D), R3.1
SDA: J1.4 (RING2), J2.4 (RING2), J4.4 (RING2), LICK.4 (RING2), Q1.3 (D), R8.2


Board: 2 copper layers, 92.9 x 35.6 mm, 30 parts (0 on the bottom side), 21 nets.

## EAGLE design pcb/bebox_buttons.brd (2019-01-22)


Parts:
J1: SJ-435107RS; CUI_SJ-435107RS
LED1, LED2: LED5MM
R1, R4: 330; 0207/10
U1: MCP23008-E/P; DIP254P762X533-18
U$2, U$3, U$4, U$5: CHERRY-MX

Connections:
5V: J1.2 (TIP), U1.5 (A0), U1.6 (*RESET), U1.18 (VDD)
GND: J1.1 (SLEEVE), LED1.K (C), LED2.K (C), U1.3 (A2), U1.4 (A1), U1.9 (VSS), U$2.SW2 (PIN-2), U$3.SW2 (PIN-2), U$4.SW2 (PIN-2), U$5.SW2 (PIN-2)
unnamed: U1.10 (GP0), U$5.SW1 (PIN-1)
unnamed: U1.11 (GP1), U$4.SW1 (PIN-1)
unnamed: U1.12 (GP2), U$3.SW1 (PIN-1)
unnamed: U1.13 (GP3), U$2.SW1 (PIN-1)
unnamed: LED1.A, R1.1
unnamed: R1.2, U1.14 (GP4)
unnamed: LED2.A, R4.2
unnamed: J1.4 (RING2), U1.2 (SDA)
unnamed: R4.1, U1.15 (GP5)
SCL: J1.3 (RING1), U1.1 (SCL)


Board: 2 copper layers, 44.4 x 49.2 mm, 10 parts (0 on the bottom side), 12 nets.

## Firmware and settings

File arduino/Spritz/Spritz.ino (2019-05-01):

// Necessary for the encoder to read the interrupt pins
#define ENCODER_USE_INTERRUPTS
#define __SAMD51__ 1
//#define CORE_NUM_INTERRUPT 20
//#define CORE_INT2_PIN 2
//#define CORE_INT3_PIN 3

#include <SPI.h>
#include "Wire.h"
#include "Encoder.h"
#include <Adafruit_GFX.h>
#include <Adafruit_SSD1306.h>
#include "Montserrat_Medium20pt7b.h"
#include "Montserrat_Regular6pt7b.h"

// Settings
#define SCREEN_WIDTH 128 // OLED display width, in pixels
#define SCREEN_HEIGHT 64 // OLED display height, in pixels

// Pins
// Reference https://github.com/adafruit/ArduinoCore-samd/blob/master/variants/itsybitsy_m4/variant.h
#define OLED_MOSI  PIN_SPI_MOSI  // Maybe should switch to hardware PIN_SPI_MOSI
#define OLED_CLK   PIN_SPI_SCK   // Maybe should switch to hardware PIN_SPI_SCK
#define OLED_DC    PIN_A3
#define OLED_CS    PIN_A5
#define OLED_RESET PIN_A4

#define ENCODER1    9
#define ENCODER2    10
#define ENCODER_BUT 7
#define TOP_BUT     11
#define BOT_BUT     12
#define LED_PIN     4
#define OUT_PIN     3

Adafruit_SSD1306 display(SCREEN_WIDTH, SCREEN_HEIGHT,
  OLED_MOSI, OLED_CLK, OLED_DC, OLED_RESET, OLED_CS);
Encoder encoder(ENCODER1, ENCODER2);

long encoder_pos = 0;
float pulse_ms = 5.0;
float pulse_sec = 0.5;
bool pulsing = false;
bool active_output = false;
int mode = 0;

unsigned long int now;
unsigned long int now_micro;
unsigned long int pulse_start;
unsigned long int mode_last = 0;
unsigned long int pulsing_last = 0;

bool drawNext = false;

void setup() {
  Serial.begin(9600);

  if(!display.begin(SSD1306_SWITCHCAPVCC)) {
    Serial.println(F("SSD1306 allocation failed"));
    for(;;); // Don't proceed, loop forever
  }
  
  encoder_pos = encoder.read();
  
  pinMode(ENCODER_BUT, INPUT_PULLUP);
  pinMode(TOP_BUT, INPUT_PULLUP);
  pinMode(BOT_BUT, INPUT_PULLUP);
  pinMode(LED_PIN, OUTPUT);
  pinMode(OUT_PIN, OUTPUT);

  attachInterrupt(digitalPinToInterrupt(TOP_BUT), interruptMode, FALLING);
  attachInterrupt(digitalPinToInterrupt(BOT_BUT), interruptPulse, FALLING);

  // Clear the buffer
  display.setTextColor(WHITE);        // Draw white text
  display.clearDisplay();
  
  drawDispense();
}

void loop() {
  now = millis();
  updateEncoder();
  calculateStim();

  if (drawNext) {
    drawDispense();
    drawNext = false;
  }
}

void interruptMode() {
  if (now - mode_last > 400) {
    mode = (mode + 1)%2;
    mode_last = now;
  }
  
  drawNext = true;
}

void updateEncoder() {
  int delta;
  long pos;
  
  pos = encoder.read();
  if (abs(pos - encoder_pos) > 3 && mode == 0) {
    delta = (pos - encoder_pos)/4;

    if (pulse_ms < 10 || (pulse_ms == 10 && delta < 0)) {
      pulse_ms += float(delta)/2;
    }
    else if (pulse_ms < 20 || (pulse_ms == 20 && delta < 0)) {
      pulse_ms += delta;
      pulse_ms = round(pulse_ms);
    }
    else if (pulse_ms < 50 || (pulse_ms == 50 && delta < 0)) {
      pulse_ms += delta*2;
    }
    else if (pulse_ms < 100 || (pulse_ms == 100 && delta < 0)) {
      pulse_ms += delta*5;
    }
    else {
      pulse_ms += delta*50;
    }

    if (pulse_ms < 0.5) {
      pulse_ms = 0.5;
    }
    else if (pulse_ms > 500) {
      pulse_ms = 500;
    }

    drawDispense();
    encoder_pos = pos;
  }
  
  else if (abs(pos - encoder_pos) > 3 && mode == 1) {
    delta = (pos - encoder_pos)/4;

    if (pulse_sec < 2.0 || (pulse_sec == 2.0 && delta < 0)) {
      pulse_sec += float(delta)/10;
    }
    else {
       pulse_sec += float(delta)/5;
    }

    if (pulse_sec < 0.1) {
      pulse_sec = 0.1;
    }
    else if (pulse_sec > 20) {
      pulse_sec = 20;
    }

    drawDispense();
    encoder_pos = pos;
  }
}

// DRAWING
// ---------------------------------------------------------------
void drawDispense() {
  display.clearDisplay();
  
  // Dispensing code
  if (pulsing) {
    display.fillRect(0, 0, 2, display.height(), WHITE);
  }

  // Main draw code
  // BIG
  display.setFont(&Montserrat_Medium20pt7b);
  display.setCursor(20, 60);

  if (mode == 0) {
    display.print(pulse_ms, pulse_ms < 10 ? 1 : 0);
  }
  else {
    display.print(pulse_sec, pulse_sec < 10 ? 1 : 0);
  }

  // Small fonts
  display.setFont(&Montserrat_Regular6pt7b);
  
  display.setCursor(110, 60);
  if (mode == 0) {display.print("ms");}
  else {display.print("/s");}

  // Mode code
  display.setCursor(10, 16);
  if (mode == 0) {display.print("PUFF");}
  else {display.print("RATE");}

  // Mode code
  display.setCursor(80, 16);
  if (mode == 0) {
    display.print(pulse_sec, pulse_sec < 10 ? 1 : 0);
    display.setCursor(110, 16);
    display.print("/s");
  }
  else {
    display.print(pulse_ms, pulse_ms < 10 ? 1 : 0);
    display.setCursor(110, 16);
    display.print("ms");
  }
  
  display.display();
}


void interruptPulse() {
  if (now - pulsing_last > 400) {
    if (!pulsing) {
      pulsing = true;
      pulse_start = micros();
    }
    else if (!digitalRead(BOT_BUT) && pulsing) {
      pulsing = false;
    }
    
    pulsing_last = now;
    drawNext = true;
  }
}

// Calculate and apply optogenetic stimulus
void calculateStim() {
  if (pulsing) {
    bool tmpoutput = false;
    now_micro = micros();
    unsigned long int currenttime = now_micro - pulse_start;
    
    // If during the on section of the repeat
    float window = pulse_sec*1000000.0;
    //float window = 1000000.0/pars.frequencyHz;
    if (fmod((float) currenttime, window) < pulse_ms*1000.0) {
      tmpoutput = true;
    }
    
    // Write the output
    if (tmpoutput && !active_output) {
      digitalWrite(OUT_PIN, HIGH);
      digitalWrite(LED_PIN, HIGH);
      pulse_start = now_micro;
      active_output = true;
    }
    else if (!tmpoutput && active_output) {
      digitalWrite(OUT_PIN, LOW);
      digitalWrite(LED_PIN, LOW);
      active_output = false;
    }
  }
  else {
    digitalWrite(OUT_PIN, LOW);
    digitalWrite(LED_PIN, LOW);
  }
}

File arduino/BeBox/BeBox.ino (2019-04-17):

#include <Wire.h>
#include "Adafruit_MCP23008.h"
#include "mpr121.h"

#define LICK_MIN_MS 60
#define SOLENOID_MIN_MS 20

bool active_but[4] = {false, false, false, false};  // Which buttons are active
bool active_bnc[4] = {false, false, false, false};  // Which BNCs are active
int solenoid_on = -1;  // There can only be one solenoid on at a time
unsigned long int solenoid_change = 0;  // The solenoids can only change every N ms

bool touchStates[12];  // to keep track of the previous touch states
int active_lick = -1;  // Which lick option is selected
int lick_ttl_on = -1;
unsigned long int last_lick = 0;  // The time of the last lick
unsigned long int last_lick_ttl = 0;  // The time of the last lick
bool lick_change = false;

unsigned long int now = 0;

Adafruit_MCP23008 bebox_but;
Adafruit_MCP23008 bebox_bnc;

void setup() {
  // Initialize the BNC sub-box
  bebox_bnc.begin(0);
  for (int i = 1; i < 5; i++) {
    bebox_bnc.pinMode(i, INPUT);
  }
  bebox_bnc.pinMode(0, OUTPUT);  // lick  
  
  // Initialize the button sub-box
  bebox_but.begin(1);
  for (int i = 0; i < 4; i++) {
    bebox_but.pinMode(i, INPUT);
    bebox_but.pullUp(i, HIGH);  // turn on a 100K pullup internally
  }
  bebox_but.pinMode(4, OUTPUT);  // red LED
  bebox_but.pinMode(5, OUTPUT);  // yellow LED

  // Initialize the solenoid outputs
  for (int i = 3; i < 7; i++) {
    pinMode(i, OUTPUT);
    digitalWrite(i, LOW);
  }

  // Initialize the lick detection
  Wire.begin();
  mpr121_setup();
}

void loop() {
  now = millis();
  checkBNCs();
  checkButtons();
  setSolenoids();
  
  checkLicks();
  if (lick_change) {
    setLicks();
    lick_change = false;
  }
}

// Check which BNCs are currently on
void checkBNCs() {
  int mcpio = bebox_bnc.readGPIO();
  for (int i = 1; i < 5; i++) {
    active_bnc[i-1] = ((mcpio >> i) & 0x1);
  }
}

// Check which buttons are currently on
void checkButtons() {
  int mcpio = bebox_but.readGPIO();
  for (int i = 0; i < 4; i++) {
    active_but[i] = !((mcpio >> i) & 0x1);
  }
}

// Set which solenoid is active
void setSolenoids() {
  if (now - solenoid_change > SOLENOID_MIN_MS) {
    if (solenoid_on > -1 and !active_bnc[solenoid_on] and !active_but[solenoid_on]) {
      digitalWrite(6 - solenoid_on, LOW);
      solenoid_on = -1;
      solenoid_change = now;
    }
    else {
      int i = 0;
      while (solenoid_on < 0 && i < 4) {
        if (active_bnc[i] || active_but[i]) {
          solenoid_on = i;
          digitalWrite(6 - solenoid_on, HIGH);
          solenoid_change = now;
        }
        i++;
      }
    }
  }
}

// Check for a lick, if found, pass on to TTL and LED
void checkLicks() {
  if (now - last_lick > LICK_MIN_MS) {
    //read the touch state from the MPR121
    Wire.requestFrom(0x5A,2); 
    byte LSB = Wire.read();
    byte MSB = Wire.read();
    uint16_t touched = ((MSB << 8) | LSB); //16bits that make up the touch states

    bool licks_found[2] = {false, false};
    for (int j = 0; j < 2; j++) {
      for (int i = j*6+0; i < j*6+6; i++) {  // Check what electrodes were pressed
        if (touched & (1 << i) && !touchStates[i]) {
          licks_found[j] = true;
        }
        
        touchStates[i] = touched & (1 << i);
      }
    }

    if (active_lick > -1 && !licks_found[active_lick]) {
      active_lick = -1;
      last_lick = now;
      lick_change = true;
    }
    else if (active_lick == -1) {
      for (int j = 1; j >= 0; j--) {
        if (licks_found[j]) {
          active_lick = j;
          last_lick = now;
          lick_change = true;
        }
      }
    }
  }
}

// Set the LED and TTL for licking
void setLicks() {
  bebox_bnc.digitalWrite(0, LOW);
  bebox_but.digitalWrite(4, LOW);
  bebox_but.digitalWrite(5, LOW);
  
  if (active_lick == 0) {
    bebox_bnc.digitalWrite(0, HIGH);
    bebox_but.digitalWrite(4, HIGH);
  }
  else if (active_lick == 1) {
    bebox_bnc.digitalWrite(0, HIGH);
    bebox_but.digitalWrite(5, HIGH);
  }
}

// ==============================================================
// The following us only for setting up the lick detector
void mpr121_setup(void){

  set_register(0x5A, ELE_CFG, 0x00); 
  
  // Section A - Controls filtering when data is > baseline.
  set_register(0x5A, MHD_R, 0x01);
  set_register(0x5A, NHD_R, 0x01);
  set_register(0x5A, NCL_R, 0x00);
  set_register(0x5A, FDL_R, 0x00);

  // Section B - Controls filtering when data is < baseline.
  set_register(0x5A, MHD_F, 0x01);
  set_register(0x5A, NHD_F, 0x01);
  set_register(0x5A, NCL_F, 0xFF);
  set_register(0x5A, FDL_F, 0x02);
  
  // Section C - Sets touch and release thresholds for each electrode
  set_register(0x5A, ELE0_T, TOU_THRESH);
  set_register(0x5A, ELE0_R, REL_THRESH);
 
  set_register(0x5A, ELE1_T, TOU_THRESH);
  set_register(0x5A, ELE1_R, REL_THRESH);
  
  set_register(0x5A, ELE2_T, TOU_THRESH);
  set_register(0x5A, ELE2_R, REL_THRESH);
  
  set_register(0x5A, ELE3_T, TOU_THRESH);
  set_register(0x5A, ELE3_R, REL_THRESH);
  
  set_register(0x5A, ELE4_T, TOU_THRESH);
  set_register(0x5A, ELE4_R, REL_THRESH);
  
  set_register(0x5A, ELE5_T, TOU_THRESH);
  set_register(0x5A, ELE5_R, REL_THRESH);
  
  set_register(0x5A, ELE6_T, TOU_THRESH);
  set_register(0x5A, ELE6_R, REL_THRESH);
  
  set_register(0x5A, ELE7_T, TOU_THRESH);
  set_register(0x5A, ELE7_R, REL_THRESH);
  
  set_register(0x5A, ELE8_T, TOU_THRESH);
  set_register(0x5A, ELE8_R, REL_THRESH);
  
  set_register(0x5A, ELE9_T, TOU_THRESH);
  set_register(0x5A, ELE9_R, REL_THRESH);
  
  set_register(0x5A, ELE10_T, TOU_THRESH);
  set_register(0x5A, ELE10_R, REL_THRESH);
  
  set_register(0x5A, ELE11_T, TOU_THRESH);
  set_register(0x5A, ELE11_R, REL_THRESH);
  
  // Section D
  // Set the Filter Configuration
  // Set ESI2
  set_register(0x5A, FIL_CFG, 0x04);
  
  // Section E
  // Electrode Configuration
  // Set ELE_CFG to 0x00 to return to standby mode
  set_register(0x5A, ELE_CFG, 0x0C);  // Enables all 12 Electrodes
  
  
  // Section F
  // Enable Auto Config and auto Reconfig
  /*set_register(0x5A, ATO_CFG0, 0x0B);
  set_register(0x5A, ATO_CFGU, 0xC9);  // USL = (Vdd-0.7)/vdd*256 = 0xC9 @3.3V   set_register(0x5A, ATO_CFGL, 0x82);  // LSL = 0.65*USL = 0x82 @3.3V
  set_register(0x5A, ATO_CFGT, 0xB5);*/  // Target = 0.9*USL = 0xB5 @3.3V
  
  set_register(0x5A, ELE_CFG, 0x0C);
  
}

void set_register(int address, unsigned char r, unsigned char v){
    Wire.beginTransmission(address);
    Wire.write(r);
    Wire.write(v);
    Wire.endTransmission();
}

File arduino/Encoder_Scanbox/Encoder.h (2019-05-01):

/* Encoder Library, for measuring quadrature encoded signals
 * http://www.pjrc.com/teensy/td_libs_Encoder.html
 * Copyright (c) 2011,2013 PJRC.COM, LLC - Paul Stoffregen <paul@pjrc.com>
 *
 * Version 1.2 - fix -2 bug in C-only code
 * Version 1.1 - expand to support boards with up to 60 interrupts
 * Version 1.0 - initial release
 * 
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
 * THE SOFTWARE IS PROVIDED "AS IS", WITHOUT WARRANTY OF ANY KIND, EXPRESS OR
 * IMPLIED, INCLUDING BUT NOT LIMITED TO THE WARRANTIES OF MERCHANTABILITY,
 * FITNESS FOR A PARTICULAR PURPOSE AND NONINFRINGEMENT. IN NO EVENT SHALL THE
 * AUTHORS OR COPYRIGHT HOLDERS BE LIABLE FOR ANY CLAIM, DAMAGES OR OTHER
 * LIABILITY, WHETHER IN AN ACTION OF CONTRACT, TORT OR OTHERWISE, ARISING FROM,
 * OUT OF OR IN CONNECTION WITH THE SOFTWARE OR THE USE OR OTHER DEALINGS IN
 * THE SOFTWARE.
 */


#ifndef Encoder_h_
#define Encoder_h_

#if defined(ARDUINO) && ARDUINO >= 100
#include "Arduino.h"
#elif defined(WIRING)
#include "Wiring.h"
#else
#include "WProgram.h"
#include "pins_arduino.h"
#endif

#include "utility/direct_pin_read.h"

#if defined(ENCODER_USE_INTERRUPTS) || !defined(z)
#define ENCODER_USE_INTERRUPTS
#define ENCODER_ARGLIST_SIZE CORE_NUM_INTERRUPT
#include "utility/interrupt_pins.h"
#ifdef ENCODER_OPTIMIZE_INTERRUPTS
#include "utility/interrupt_config.h"
#endif
#else
#define ENCODER_ARGLIST_SIZE 0
#endif



// All the data needed by interrupts is consolidated into this ugly struct
// to facilitate assembly language optimizing of the speed critical update.
// The assembly code uses auto-incrementing addressing modes, so the struct
// must remain in exactly this order.
typedef struct {
  volatile IO_REG_TYPE * pin1_register;
  volatile IO_REG_TYPE * pin2_register;
  IO_REG_TYPE            pin1_bitmask;
  IO_REG_TYPE            pin2_bitmask;
  uint8_t                state;
  int32_t                position;
} Encoder_internal_state_t;

class Encoder
{
public:
  Encoder(uint8_t pin1, uint8_t pin2) {
    #ifdef INPUT_PULLUP
    pinMode(pin1, INPUT_PULLUP);
    pinMode(pin2, INPUT_PULLUP);
    #else
    pinMode(pin1, INPUT);
    digitalWrite(pin1, HIGH);
    pinMode(pin2, INPUT);
    digitalWrite(pin2, HIGH);
    #endif
    encoder.pin1_register = PIN_TO_BASEREG(pin1);
    encoder.pin1_bitmask = PIN_TO_BITMASK(pin1);
    encoder.pin2_register = PIN_TO_BASEREG(pin2);
    encoder.pin2_bitmask = PIN_TO_BITMASK(pin2);
    encoder.position = 0;
    // allow time for a passive R-C filter to charge
    // through the pullup resistors, before reading
    // the initial state
    delayMicroseconds(2000);
    uint8_t s = 0;
    if (DIRECT_PIN_READ(encoder.pin1_register, encoder.pin1_bitmask)) s |= 1;
    if (DIRECT_PIN_READ(encoder.pin2_register, encoder.pin2_bitmask)) s |= 2;
    encoder.state = s;
#ifdef ENCODER_USE_INTERRUPTS
    interrupts_in_use = attach_interrupt(pin1, &encoder);
    interrupts_in_use += attach_interrupt(pin2, &encoder);
#endif
    //update_finishup();  // to force linker to include the code (does not work)
  }


#ifdef ENCODER_USE_INTERRUPTS
  inline int32_t read() {
    if (interrupts_in_use < 2) {
      noInterrupts();
      update(&encoder);
    } else {
      noInterrupts();
    }
    int32_t ret = encoder.position;
    interrupts();
    return ret;
  }
  inline int32_t readAndReset() {
    if (interrupts_in_use < 2) {
      noInterrupts();
      update(&encoder);
    } else {
      noInterrupts();
    }
    int32_t ret = encoder.position;
    encoder.position = 0;
    interrupts();
    return ret;
  }
  inline void write(int32_t p) {
    noInterrupts();
    encoder.position = p;
    interrupts();
  }
#else
  inline int32_t read() {
    update(&encoder);
    return encoder.position;
  }
  inline int32_t readAndReset() {
    update(&encoder);
    int32_t ret = encoder.position;
    encoder.position = 0;
    return ret;
  }
  inline void write(int32_t p) {
    encoder.position = p;
  }
#endif
private:
  Encoder_internal_state_t encoder;
#ifdef ENCODER_USE_INTERRUPTS
  uint8_t interrupts_in_use;
#endif
public:
  static Encoder_internal_state_t * interruptArgs[ENCODER_ARGLIST_SIZE];

//                           _______         _______       
//               Pin1 ______|       |_______|       |______ Pin1
// negative <---         _______         _______         __      --> positive
//               Pin2 __|       |_______|       |_______|   Pin2

    //  new new old old
    //  pin2  pin1  pin2  pin1  Result
    //  ----  ----  ----  ----  ------
    //  0 0 0 0 no movement
    //  0 0 0 1 +1
    //  0 0 1 0 -1
    //  0 0 1 1 +2  (assume pin1 edges only)
    //  0 1 0 0 -1
    //  0 1 0 1 no movement
    //  0 1 1 0 -2  (assume pin1 edges only)
    //  0 1 1 1 +1
    //  1 0 0 0 +1
    //  1 0 0 1 -2  (assume pin1 edges only)
    //  1 0 1 0 no movement
    //  1 0 1 1 -1
    //  1 1 0 0 +2  (assume pin1 edges only)
    //  1 1 0 1 -1
    //  1 1 1 0 +1
    //  1 1 1 1 no movement
/*
  // Simple, easy-to-read "documentation" version :-)
  //
  void update(void) {
    uint8_t s = state & 3;
    if (digitalRead(pin1)) s |= 4;
    if (digitalRead(pin2)) s |= 8;
    switch (s) {
      case 0: case 5: case 10: case 15:
        break;
      case 1: case 7: case 8: case 14:
        position++; break;
      case 2: case 4: case 11: case 13:
        position--; break;
      case 3: case 12:
        position += 2; break;
      default:
        position -= 2; break;
    }
    state = (s >> 2);
  }
*/
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

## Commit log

2019-01-22 Completed but untested boards. Note that there is an extra solenoid position.
    [bebox.brd, bebox.sch]
2019-01-22 Updated to version 1.1 a BNC board that connects to the main board via i2c. It is untested but complete.
    [bebox_bnc.brd, bebox_bnc.sch]
2019-01-22 Version 1.1 of a completed but untested daughterboard that registers licks and controls solenoids.
    [bebox_buttons.brd, bebox_buttons.sch]
2019-01-22 Files necessary for the wheel and associated components.
    [wheel arduino holder.stl, wheel axle.stl, wheel encoder board holder.stl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]
2019-01-22 Necessary files for controlling the arduino in the boards.
2019-01-22 Moved PCB files to their own location.
    [bebox.brd, bebox.sch, bebox_bnc.brd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]
2019-01-28 Added encoder codes.
2019-01-28 Updated the README to include the encoder.
2019-01-28 Added lickspout files and definitions.
    [lickspout base capacitance.scad, lickspout base capacitance.stl, lickspout bitube water.stl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]
2019-03-15 Updated the boards.
    [bebox_encoder.brd, bebox_encoder.sch, bebox_main.brd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]
2019-03-15 Updated the arduino code to correctly reflect dumberbox.
    [BeBox.ino, Dumberbox.ino, encoder_scanbox.ino]
2019-03-15 Moved arduino files into their own directories.
2019-03-15 Updated to include encoder board.
2019-03-15 Updated to include all components necessary for the current boards.
2019-03-15 Added info about the syringe pump.
    [syringe pump box.stl, syringe pump carriage.stl, syringe_pump.sch]
2019-03-15 Updated to include syringe pump hardware.
2019-04-11 Renamed original bebox main and udpated the footprint of the switch.
    [bebox_main_trinket.brd, bebox_main_trinket.sch]
2019-04-11 Added new bebox main that works with 3.3V Adafruit Itsy Bitsy, which is the replacement for the now depracated Pro Trinket.
    [bebox_main_itsybitsy.brd, bebox_main_itsybitsy.sch]
2019-04-11 Updated screenprints.
    [bebox_encoder.brd, bebox_main_itsybitsy.brd, bebox_main_itsybitsy.sch]
2019-04-11 Completed syringe pump board and schematic.
    [syringe_pump.brd, syringe_pump.sch]
2019-04-11 Completed spritzer board and schematic.
    [bebox_spritzer.brd, bebox_spritzer.sch]
2019-04-11 Completed and tested versions of each of the three BeBox containers.
    [bebox bnc bottom.stl, bebox bnc top.stl, bebox button 1.stl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]
2019-04-12 Added cable information
2019-04-14 Have updated the Arduino code and it is confirmed to work.
2019-04-14 Now have created boards that should directly connect to cables connected to the national instruments PCIe boards, rather than passing through the BNC box.
    [bebox_nidaq_2p.brd, bebox_nidaq_2p.sch, bebox_nidaq_stimulus.brd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]
2019-04-15 Previously did not have sufficient analog inputs for two photometry inputs and one digital input. Now have 4 BNC inputs.
    [bebox_nidaq_2p.brd, bebox_nidaq_2p.sch]
2019-04-17 Fixed overlap of wires to Solenoid 1 and Solenoid 2
    [bebox_bnc.brd]
2019-04-17 Reorderd pins so that they would be more general across users.
    [bebox_nidaq_stimulus.brd, bebox_nidaq_stimulus.sch]
2019-05-01 Added Spritz. Requires its own Encoder library because the current version does not work with a SAMD51, i.e. ItsyBitsy M4.
    [Encoder.h, Spritz.ino, interrupt_pins.h]
2019-05-10 Updated spacing of syringe pump and added copy of encoder library due to version issues.
    [syringe_pump.brd, syringe_pump.sch]
